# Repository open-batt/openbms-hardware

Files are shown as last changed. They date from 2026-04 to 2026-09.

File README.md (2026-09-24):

# OpenBMS






OpenBMS is an **open-source battery management system** for 2 to 7-cell Li-Ion and Li-Po battery packs. A fully integrated hardware and firmware solution for battery management and protection, providing:
-  **Fuel gauge** — measure battery capacity, state of charge, and state of health
-  **Learning algorithms** — learn battery behavior and adjust management accordingly
-  **Cell balancing** — keep multi-cell voltages in sync to prevent drift over time
-  **Protection** — guard against overcharging, overdischarging, overheating, and short circuits
-  **Communication** — talk to chargers, displays, microcontrollers, and other devices

<table>
  <tr>
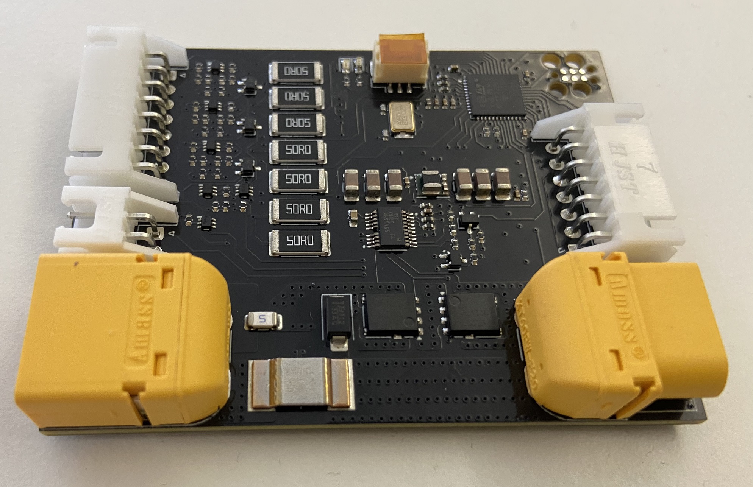
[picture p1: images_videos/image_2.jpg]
OpenBMS v3
    <td></td>
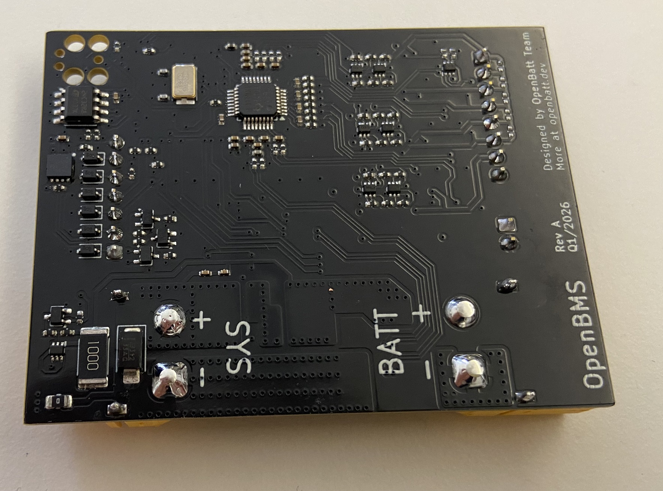
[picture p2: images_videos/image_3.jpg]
OpenBMS v4
    <td></td>
  </tr>
</table>

## Rev B is out!
Schematic and layout updated, fixes applied

## Related repositories

[OpenBMS-firmware](https://github.com/open-batt/openbms-firmware)  
[OpenBMS-test-bench](https://github.com/open-batt/openbms-test-bench-hardware)  
[OpenBMS-studio](https://github.com/open-batt/openbms-studio)

## How OpenBMS fits into system?

Battery system consists of:
- **Li-ion/Li-Po battery** — your custom 2- to 7-cell battery
- **OpenBMS** — battery management system that handles fuel gauging, cell balancing, learning algorithms, overcharge/overdischarge/overheat protection, and communication with chargers and microcontrollers
- [**Test Bench**](https://github.com/open-batt/openbms-test-bench-hardware) — a 600W dissipative resistive load for easier BMS development and testing
- **Host** — I2C/CAN interfaces, wake-up signal, can be a microcontroller, computer, etc.
- **Charger** — your custom charger, usually a CC/CV charger adjusted to your battery voltage and current
- [**OpenBMS Studio**](https://github.com/open-batt/openbms-studio) — a PC software for configuring and monitoring the BMS, visualizing data, and updating firmware using UART communication

<br/>

<video width="100%" autoplay muted loop playsinline>
  <source src="images_videos/video_2.mp4" type="video/mp4" />
</video>

## ❤️ Funding

This project is funded through [NGI0 Commons Fund](https://nlnet.nl/commonsfund), a fund established by [NLnet](https://nlnet.nl) with financial support from the European Commission's [Next Generation Internet](https://ngi.eu) program. 

[NLnet foundation logo](https://nlnet.nl)
[NGI Zero Logo](https://nlnet.nl/commonsfund)

We are very grateful to the NLnet team for helping us on our path, and we encourage you too to apply and get funds to build your project! 🚀
Learn more at the [NLnet project page](https://nlnet.nl/project/OpenBMS).

## ⚠️ Status: Work in progress

| Module | Status |
|---|---|
| OpenBMS Schematics & PCB Layout Rev A| ✅ Done |
| OpenBMS Test Bench Schematic & PCB Layout | ✅ Done |
| Revision B (Hardware improvements) |  ✅ Done |
| BMS, Test Bench & Battery Tests |  🚧 In progress |
| Documentation & Final Release | 🚧 In progress |

## Features

- 🔋 Supports pack voltages up to 30V and continuous currents up to 16A.
- ⚡ State of Charge (SoC) estimation using coulomb counting
- 🩺 State of Health (SoH) monitoring with capacity fade tracking and internal resistance estimation
- 📊 Per-cell voltage monitoring with 24-bit resolution
- 🔌 Pack and cell overcurrent protection up to 20A hardware trip (adjustable threshold)
- 🛡️ Overvoltage and undervoltage protection (adjustable thresholds)
- 🔀 Passive cell balancing for up to 7 cells
- 🔵 Battery current measurement via precision shunt resistor
- 🌡️ NTC thermistor input for battery temperature monitoring
- 🌡️ On-board ambient temperature monitoring via MCU and ADC internal sensors
- 💾 Non-volatile storage of SoC, SoH, impedance, fault history, and charge profiles (EEPROM)
- 🚌 CAN bus communication interface (up to 1 Mbit/s)
- 🔗 I2C communication interface for host integration (SMBus compatible)
- 🖥️ UART debug interface
- 🔔 Wake-up input with power-on latch for low-power system control
- 🔋 Power-down mode quiescent current < 2 µA
- 🖥️ Based on STM32L431 ARM Cortex-M4 microcontroller
  
## Overview
First, a small introduction to the project structure:
```
+-------------+       +---------------------------+       +----------------+
|             |       |         OpenBMS           |       |                |
|   Battery   |       | - - - - - - - - - - - - - |       |     System     |
| 2-7S Li-Ion | cells |   +-------+   +-------+   |       |                |
| 2-7S Li-Po  |- - - >|   |  ADC  |   |  MCU  |   |<----->|    host/load   |
|             |       |   +-------+   +-------+   | comms |                |
|             |<=====>|   +-------+   +-------+   |<=====>|     Charger    |
|             |  pwr  |   | Power |   | FETs  |   |  pwr  |                |
+-------------+       |   +-------+   +-------+   |       +----------------+
                       +-----------+--------------+
```

OpenBMS and the battery are designed to be a single, inseparable unit. Ideally, it is
connected on the first day of the battery's life and stays throughout its entire lifetime.
This way, OpenBMS learns the battery's characteristics over time and continuously tracks
its state of health and other parameters.
 
It protects the battery from overcurrent, overvoltage, and undervoltage conditions, and
balances cells to maximize pack lifetime. State of charge estimation tells you exactly how
much energy you have left, while long-term health monitoring tells you when it's time to
replace the battery.
 
The battery communicates with the host system via CAN bus or I2C. Through OpenBMS, the battery can:
- Give energy to the system (discharge)
- Take energy from the system (charge)
 
OpenBMS can be easily described with the following block diagram:

```
+---------------------------------------------------------------------------------------------------------------+
|                                                  OpenBMS                                                      |
|                                                                                                               |
|  +-----------------------+     power     +-------------------+     power     +-------------------------+      |
|  |    Battery Input      |<=============>|  Switch Circuit   |<=============>|         Output          |      |
|  | - - - - - - - - - - - |               | - - - - - - - - - |               | - - - - - - - - - - - - |      |
|  | + XT60 pwr connector  |               | + Main NFETs      |               | + XT60 pwr connector    |      |
|  | + 8-pin JST (balancer)|               | + Precharge FETs  |               | + JST (I2C,CAN,WAKE_UP) |      |
|  | + 2-pin JST (NTC)     |               +--------+----------+               +-------------------------+      |
|  +-----------------------+                         |                                      ^                   |
|            |                                       | ctr signals                          | can, i2c, wake_up |
|            | cells                                 v                                      |                   |
|  +---------------------+       SPI      +-------------------------+                       |                   |
|  |    Analog Block     |<==============>|     Digital Block       |=======================+                   |
|  |     (ADS131M08)     |                | - - - - - - - - - - - - |                                           |
|  | - - - - - - - - - - |                | + STM32L431 (Cortex-M4) |                                           |
|  | + Cell voltage x7   |                | + EEPROM                |                                           |
|  | + Pack voltage      |                | + LED indicators        |                                           |
|  | + Current           |                | + SWD / UART debug      |                                           |
|  | + PFETs cell switch |                | + I2C / CANinterfaces   |                                           |
|  +---------------------+                +-------------------------+                                           |
|                                                     ^                                                         |
|                                                     | 3.3V, wake_up                                           |
|                                          +----------+---------+                                               |
|                                          | 3.3V Power Supply  |                                               |
|                                          | - - - - - - - - -  |                                               |
|                                          | + Buck converter   |                                               |
|                                          | + Enable latch     |                                               |
|                                          +--------------------+                                               |
|                                                                                                               |
+---------------------------------------------------------------------------------------------------------------+
```

## Characteristics

| Parameter | Value |
|---|---|
| Cell count | 2 to 7 cells |
| Supported chemistries | Li-Ion, Li-Po |
| Communication interfaces | CAN bus (up to 1 Mbit/s), I2C (SMBus compatible)  |
| Maximum pack voltage | 30.1V (7 cells × 4.3V) |
| Minimum pack voltage | 4V (2 cells × 2V) |
| Maximum continuous current | 16A |
| Maximum peak current | 20A (hardware trip) |
| Current consumption (active, 7-cell, max) | 6mA |
| Current consumption (active, 7-cell, typ) | 4mA |
| Current consumption (active, 2-cell, max) | 19mA |
| Current consumption (active, 2-cell, typ) | 13mA |
| Power-down quiescent current | < 2 µA |
| Operating temperature range | -40°C to 85°C |

## License

OpenBMS is licensed under the MIT license and CERN OHL-S v2.

Check [openbatt.dev](https://openbatt.dev) for more!

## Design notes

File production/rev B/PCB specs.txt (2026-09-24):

Layers: 4
PCB thickness: 1.6mm
Min hole size: 0.3mm
Surface finish:  HASL lead free
Min track/spacing:  6/6mil
Solder mask: purple
Silkscreen: white
Finished copper:  1 oz Cu (Inner Copper:1 oz)

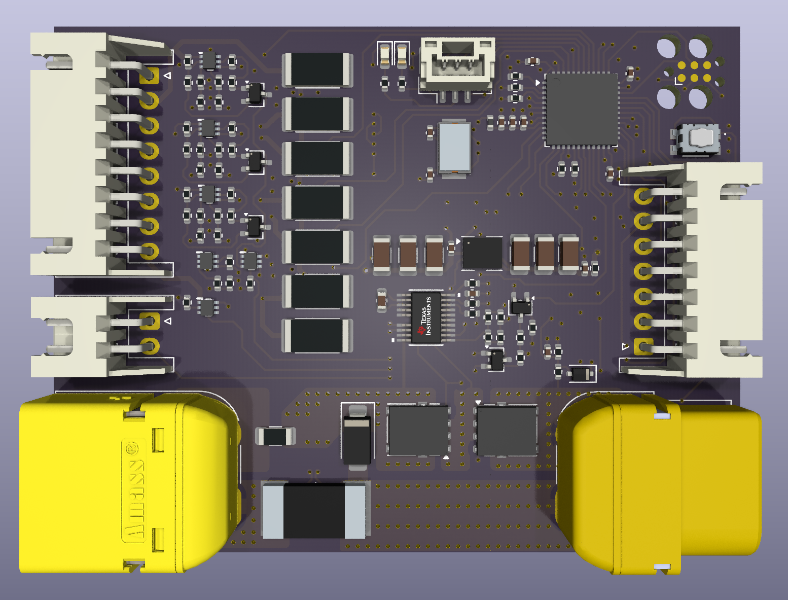
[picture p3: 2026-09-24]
production/rev B/openbms-img-1.PNG

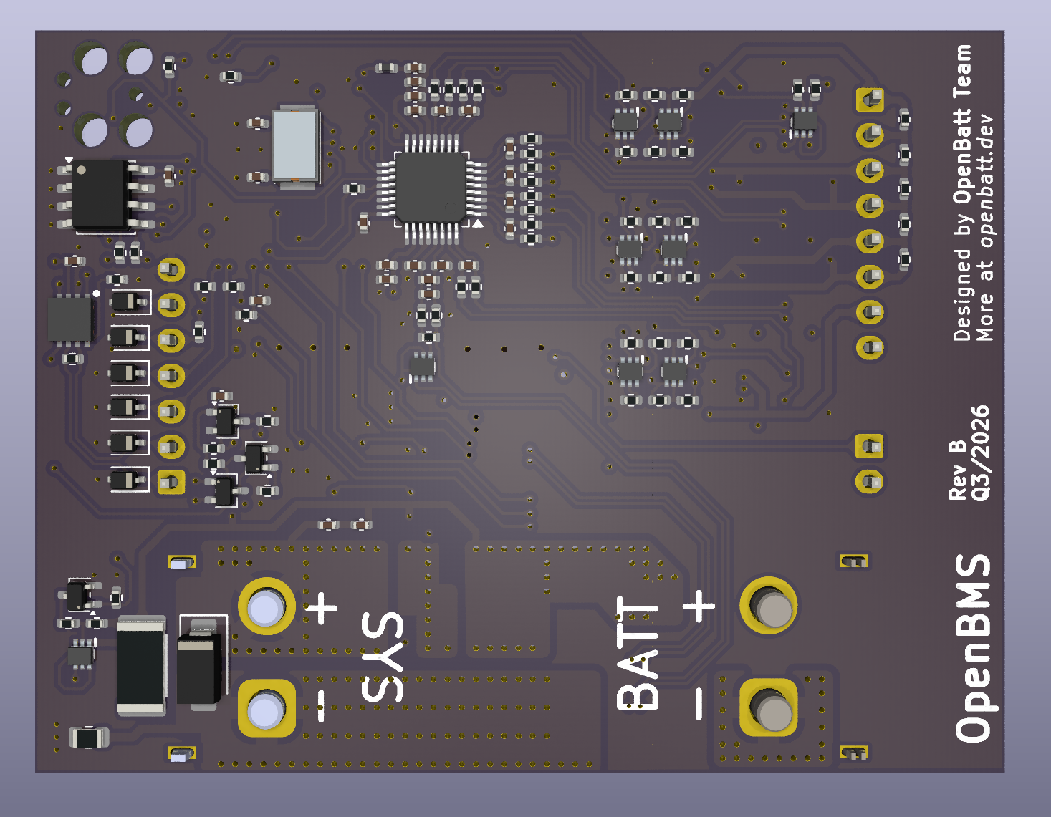
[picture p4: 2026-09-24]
production/rev B/openbms-img-2.PNG

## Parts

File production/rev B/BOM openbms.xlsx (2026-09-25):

Reference | Qty | Value | Manufacturer_Part_Number | Package
C1,C2,C4,C6,C8,C10,C11,C12,C13,C15,C17,C18,C20,C21,C22,C23,C25,C29,C30,C31,C32,C39,C43,C45 | 24 | 100n | GRM155R71A104KA01D | 0402
C3 | 1 | 100p | CL05C101JB5NNNC | 0402
C5,C9,C26,C34 | 4 | 1u | C0402C105K8PACTU | 0402
C7,C24,C35,C44 | 4 | 10n | C0402C103K5REC7411 | 0402
C14,C16,C27,C28 | 4 | 18pF | GRM1555C1H180JA01D | 0402
C19 | 1 | 220n | GRM155R71A224KE01J | 0402
C33 | 1 | 220n | CL10E224KA84PNC | 0603
C36,C37,C38,C40,C41,C42 | 6 | 10u | CL31A106MBHNNNE | 1206
D1,D2,D3,D14 | 4 | SBAT54CWT1G | SBAT54CWT1G | SOT-323
D4 | 1 | Green LED | LTST-C190GKT | 0603
D5 | 1 | Red LED | LTST-C190KRKT | 0603
D6,D7 | 2 | TVS diode P4SMA33A-Q | P4SMA33A-Q | DO-214AC
D8,D9,D10,D11,D12,D13 | 6 | TVS diode DBLC03CIQ-7 | DBLC03CIQ-7 | SOD-323
D15 | 1 | BAT54J | BAT54J | SOD-323
F1 | 1 | 25A Fuse | SF-1206HV25M-2 | 1206
J1 | 1 | 3-pin JST connector | BM03B-GHS-TBT | 3-pin JST connector
J3 | 1 | 8-pin JST connector | S8B-XH-A | 8-pin JST connector
J4 | 1 | 2-pin JST connector | S2B-XH-A | 2-pin JST connector
J5 | 1 | XT60PW-M connector | XT60PW-M | XT60PW-M connector
J6 | 1 | XT60PW-F connector | XT60PW-F | XT60PW-F connector
J7 | 1 | 7-pin JST connector | S7B-XH-A | 7-pin JST connector
L1,L2 | 2 | 600R @ 100MHz | BLM15PX601SN1D | 0402
Q1,Q2 | 2 | NTMFS5C612NLT1G | NTMFS5C612NLT1G | 5-DFN (5x6) (8-SOFL)
Q3,Q6 | 2 | BSS84AKW,115 | BSS84AKW,115 | SOT-323
Q4,Q5,Q7 | 3 | 2N7002KW | 2N7002KW | SOT-323
R1,R2,R3,R4,R6,R7,R9,R14,R21,R22,R25,R29,R30,R31,R34,R35,R49,R50,R54,R58,R62,R63,R64,R65,R66,R91,R92,R93,R94,R96,R98,R102,R109,R110,R111,R112,R116,R119 | 38 | 100k | RC0402FR-07100KL | 0402
R5,R8 | 2 | 100R | RMCF0402FT100R | 0402
R10,R11,R41,R42,R67,R68,R74 | 7 | 50R | RNCL2512FT50R0 | 2512
R12,R13,R27,R28,R56,R57,R69 | 7 | 68k,0.1% | RT0402BRD0768KL | 0402
R15,R16,R36,R37,R60,R61,R73 | 7 | 2k,0.1% | RT0402BRD072KL | 0402
R17,R20,R23,R24,R26,R32,R33,R43,R45,R48,R51,R55,R59 | 13 | 1k,0.1% | RT0402BRD071KL | 0402
R18,R19,R52,R53,R70,R71,R72,R75,R76,R78,R86,R99,R101,R117,R118 | 15 | 10k | RMCF0402FT10K0 | 0402
R38,R39,R40,R44 | 4 | 33R | RC0402FR-0733RL | 0402
R46,R47 | 2 | 100R | RC0402FR-07100RL | 0402
R77 | 1 | 330R,0.1% | RT0402BRD07330RL | 0402
R79,R80 | 2 | 470R | RC0402FR-07470RL | 0402
R81,R87,R100,R108,R113 | 5 | 0R | CR0402AJ/-000GAS | 0402
R82,R83,R84,R88,R89 | 5 | 4.7k | RC0402JR-074K7L | 0402
R85 | 1 | 120R | CRCW0402120RFKEDC | 0402
R90 | 1 | 100R | 3521100RFT | 2512
R95 | 1 | 261k | RC0402FR-07261KL | 0402
R97 | 1 | 137k | RC0402FR-07137KL | 0402
R103 | 1 | 2m | SEWF3920D2L00P9 | 3920
R115 | 1 | 0R | RMCF0805ZT0R00 | 0805
SW1 | 1 | Button | 435451019820 | 4.60mm x 2.80mm
U1,U2,U4,U6,U8,U9,U10,U18 | 8 | DMP68D1LVQ-7 | DMP68D1LVQ-7 | SOT-563
U3,U7,U11,U12,U13,U14,U22 | 7 | DMN601VK-7 | DMN601VK-7 | SOT-563
U5 | 1 | ADS131M08xPBS | ADS131M08IPBS | 32-TQFP
U15 | 1 | STM32L431CCUx | STM32L431CCU6TR | 48-UFQFPN
U16 | 1 | TCAN3413DRBR | TCAN3413DRBR | 8-VDFN
U17 | 1 | 256kbit EEPROM memory | M24256-DRMN8TP/K | 8-SOIC
U19 | 1 | TPS12000QDGXRQ1 | TPS12000QDGXRQ1 | 19-VSSOP
U20 | 1 | LMZM23600V3 | LMZM23600V3SILR | 3.8 x 3
Y1 | 1 | 8.192MHz | ECS-81.92-12-30Q-EN-TR | 5.0 x 3.2
Y2 | 1 | 8MHz | ECS-80-12-30Q-DS-TR | 5.0 x 3.2

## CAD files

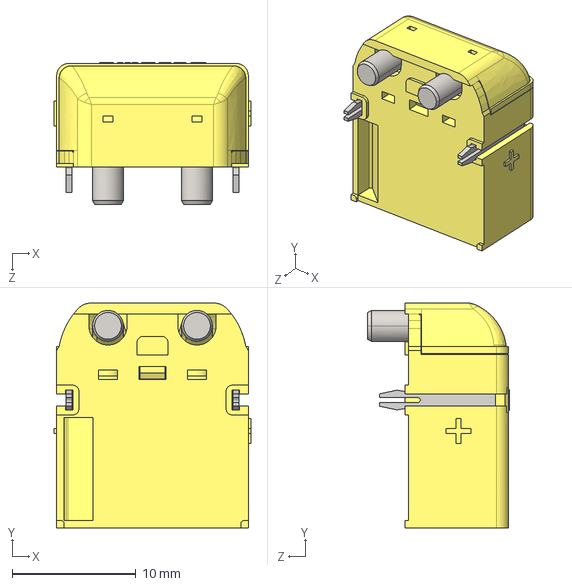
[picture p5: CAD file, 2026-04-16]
openbms/3D models/XT60PW-M.stp
15.9 x 18.2 x 11.5 mm

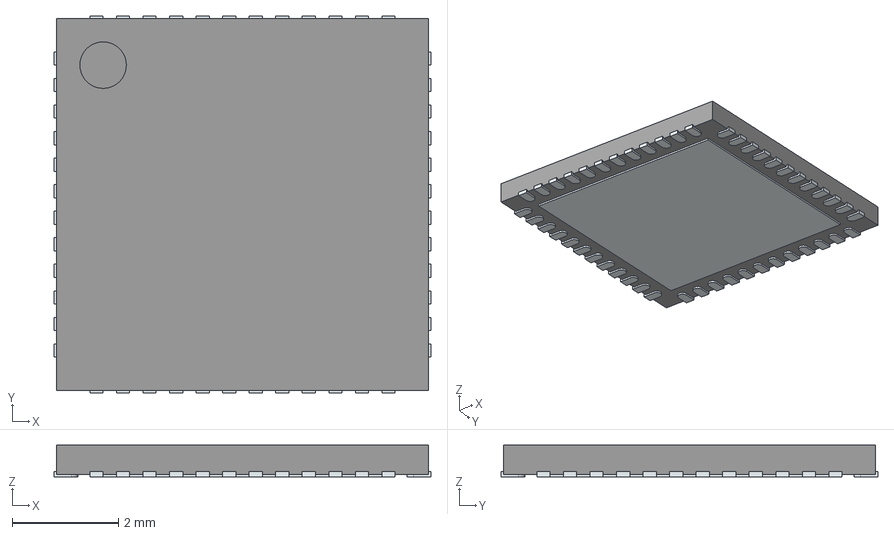
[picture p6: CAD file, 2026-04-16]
openbms/3D models/STM32L431CCU6.stp
7.10 x 7.10 x 0.6 mm
ThermalPin
PinsArrayLR
PinsArrayTB

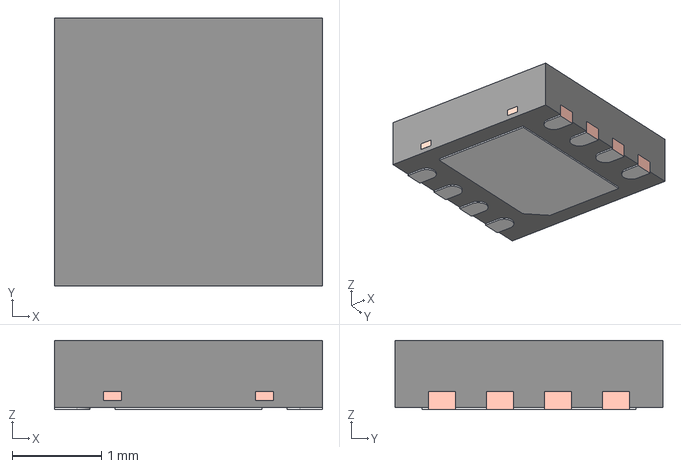
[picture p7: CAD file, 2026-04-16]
openbms/3D models/TCAN3413DRBR.stp
3.00 x 3.00 x 0.775 mm
BODY-SON
FRAME-DRB0008B

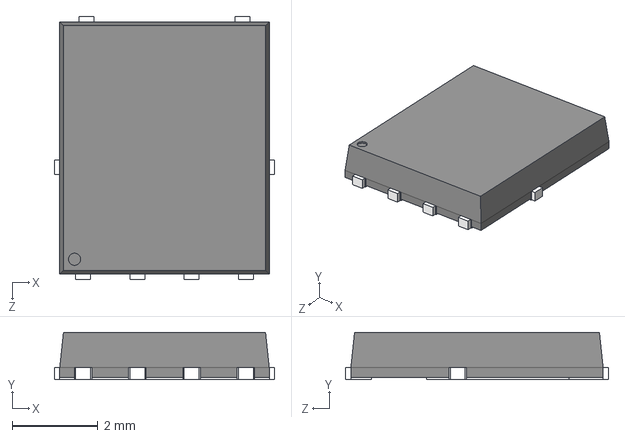
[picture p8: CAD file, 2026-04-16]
openbms/3D models/NTMFS5C612NLT1G.stp
5.15 x 1.10 x 6.15 mm

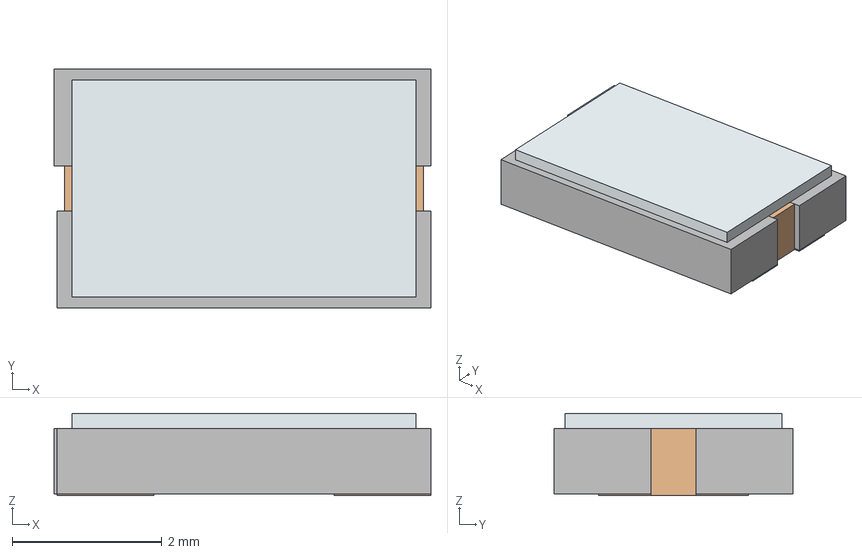
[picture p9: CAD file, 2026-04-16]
openbms/3D models/ECS-81.92-12-30Q-EN-TR.stp
5.04 x 3.20 x 1.10 mm
solidBody
solidBody1
solidLead

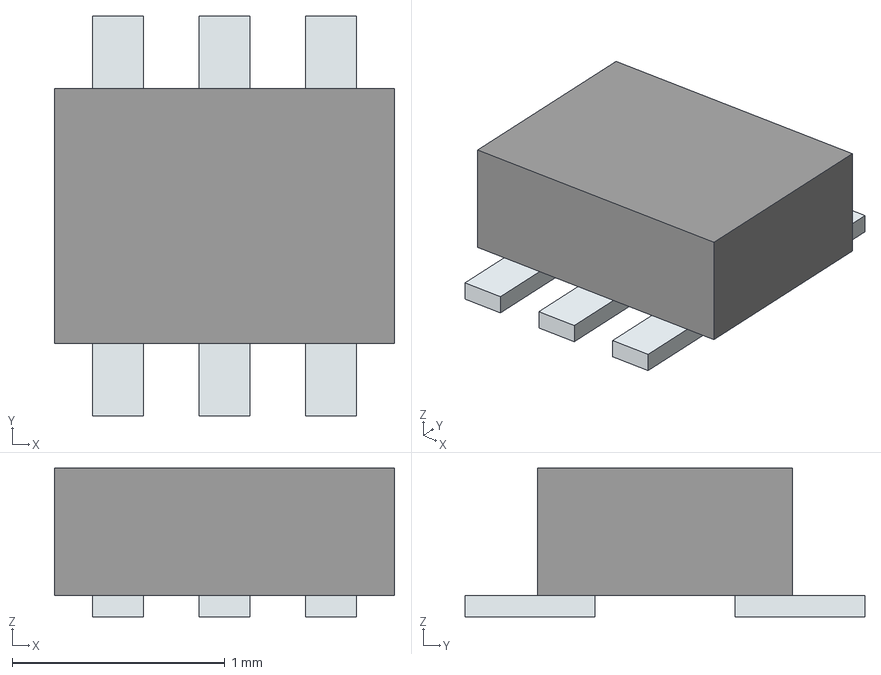
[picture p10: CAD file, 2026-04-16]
openbms/3D models/DMN601VK-7.stp
1.60 x 1.88 x 0.7 mm
Pins

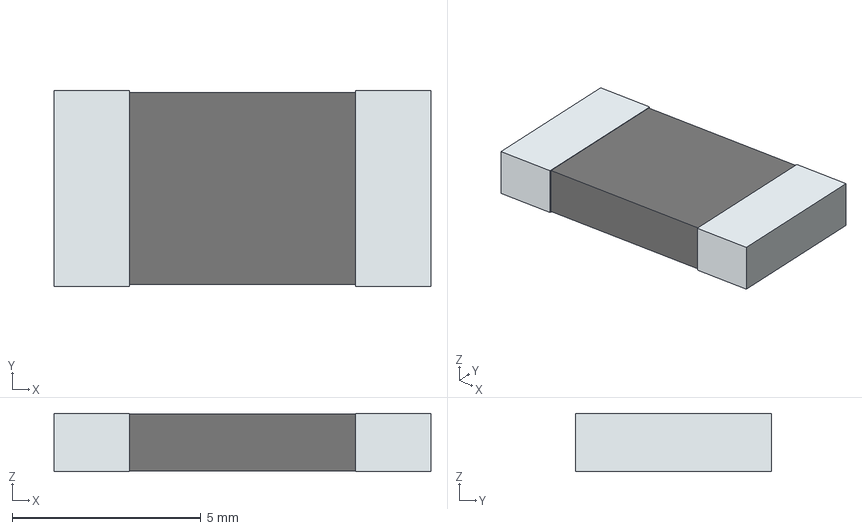
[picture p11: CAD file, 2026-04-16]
openbms/3D models/SEWF3920D2L00P9.stp
10.0 x 5.20 x 1.55 mm
term1
term2

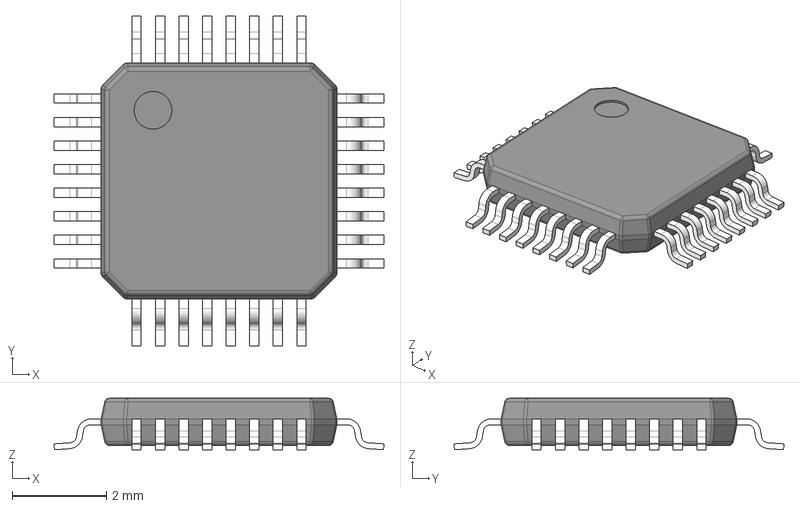
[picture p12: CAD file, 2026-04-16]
openbms/3D models/ADS131M08IPBSR.stp
7.00 x 7.00 x 1.09 mm
BODY-TQFP
LEAD-TQFP x 32
PIN1

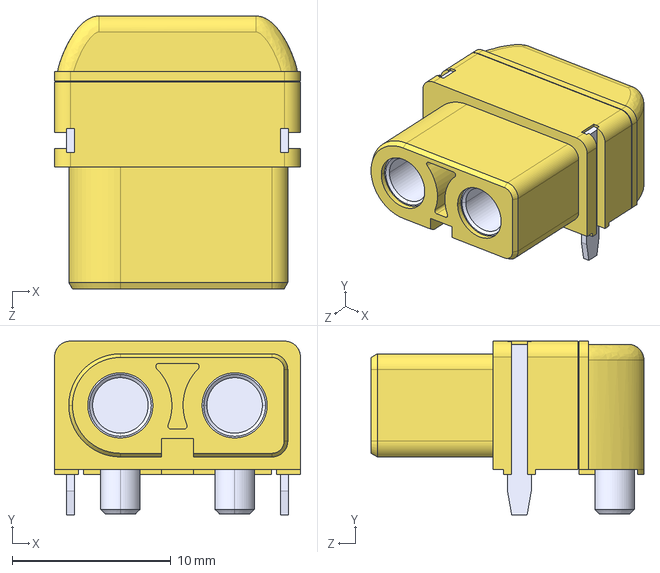
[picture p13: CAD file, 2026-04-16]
openbms/3D models/XT60PW-F.stp
15.5 x 11.0 x 17.2 mm

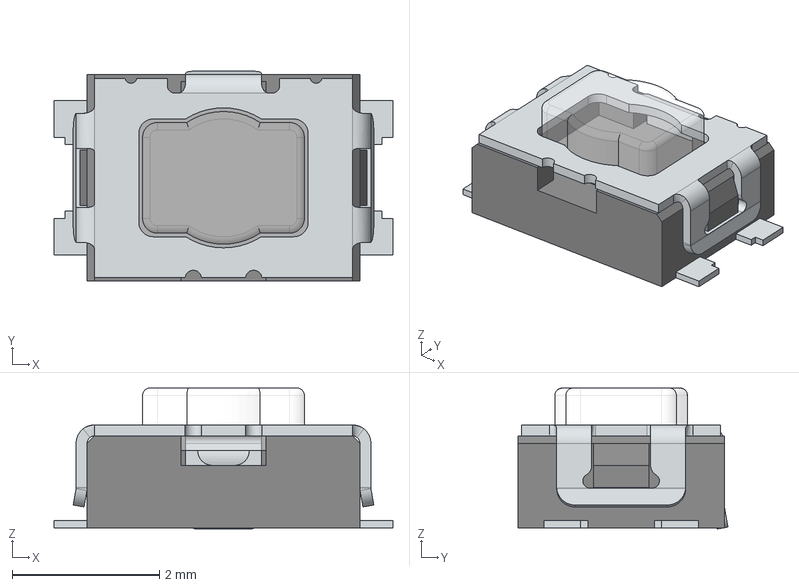
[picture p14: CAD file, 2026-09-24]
openbms/3D models/435451019820.stp
4.60 x 2.85 x 1.91 mm
Frame
Cover
Terminal
Button

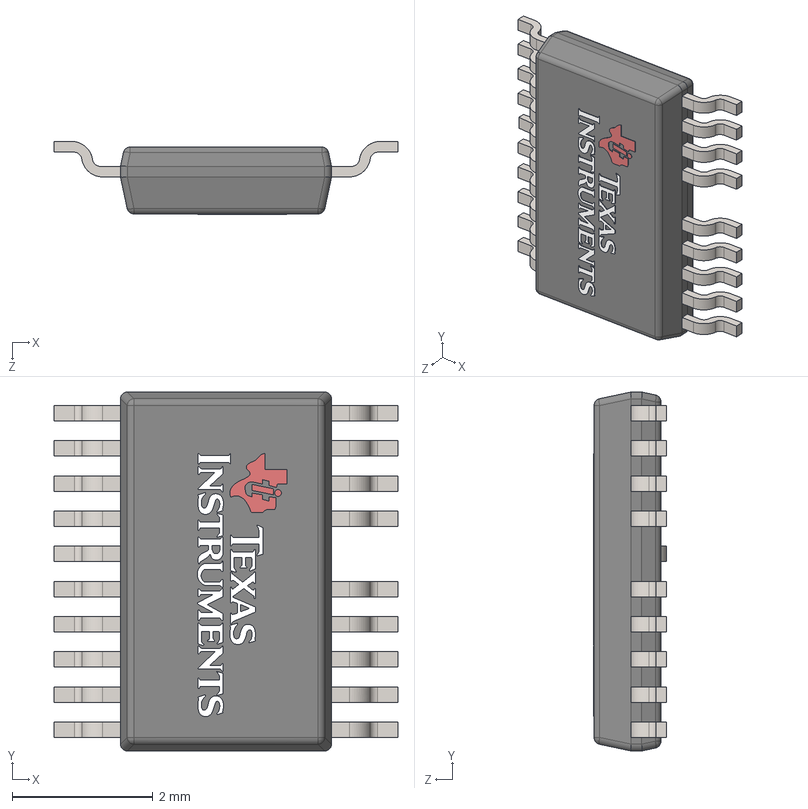
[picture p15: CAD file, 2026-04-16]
openbms/3D models/TPS12111LQDGXRQ1.stp
4.88 x 5.10 x 1.04 mm
TPS12111LQDGXRQ1
TPS12111LQDGXRQ1_4
TPS12111LQDGXRQ1_16
TPS12111LQDGXRQ1_6
TPS12111LQDGXRQ1_3
TPS12111LQDGXRQ1_7
TPS12111LQDGXRQ1_5
TPS12111LQDGXRQ1_10
TPS12111LQDGXRQ1_17
TPS12111LQDGXRQ1_8
TPS12111LQDGXRQ1_15
TPS12111LQDGXRQ1_2
TPS12111LQDGXRQ1_11
TPS12111LQDGXRQ1_19
TPS12111LQDGXRQ1_18
TPS12111LQDGXRQ1_9
TPS12111LQDGXRQ1_12
TPS12111LQDGXRQ1_14
TPS12111LQDGXRQ1_1
TPS12111LQDGXRQ1_13
Texas Instruments

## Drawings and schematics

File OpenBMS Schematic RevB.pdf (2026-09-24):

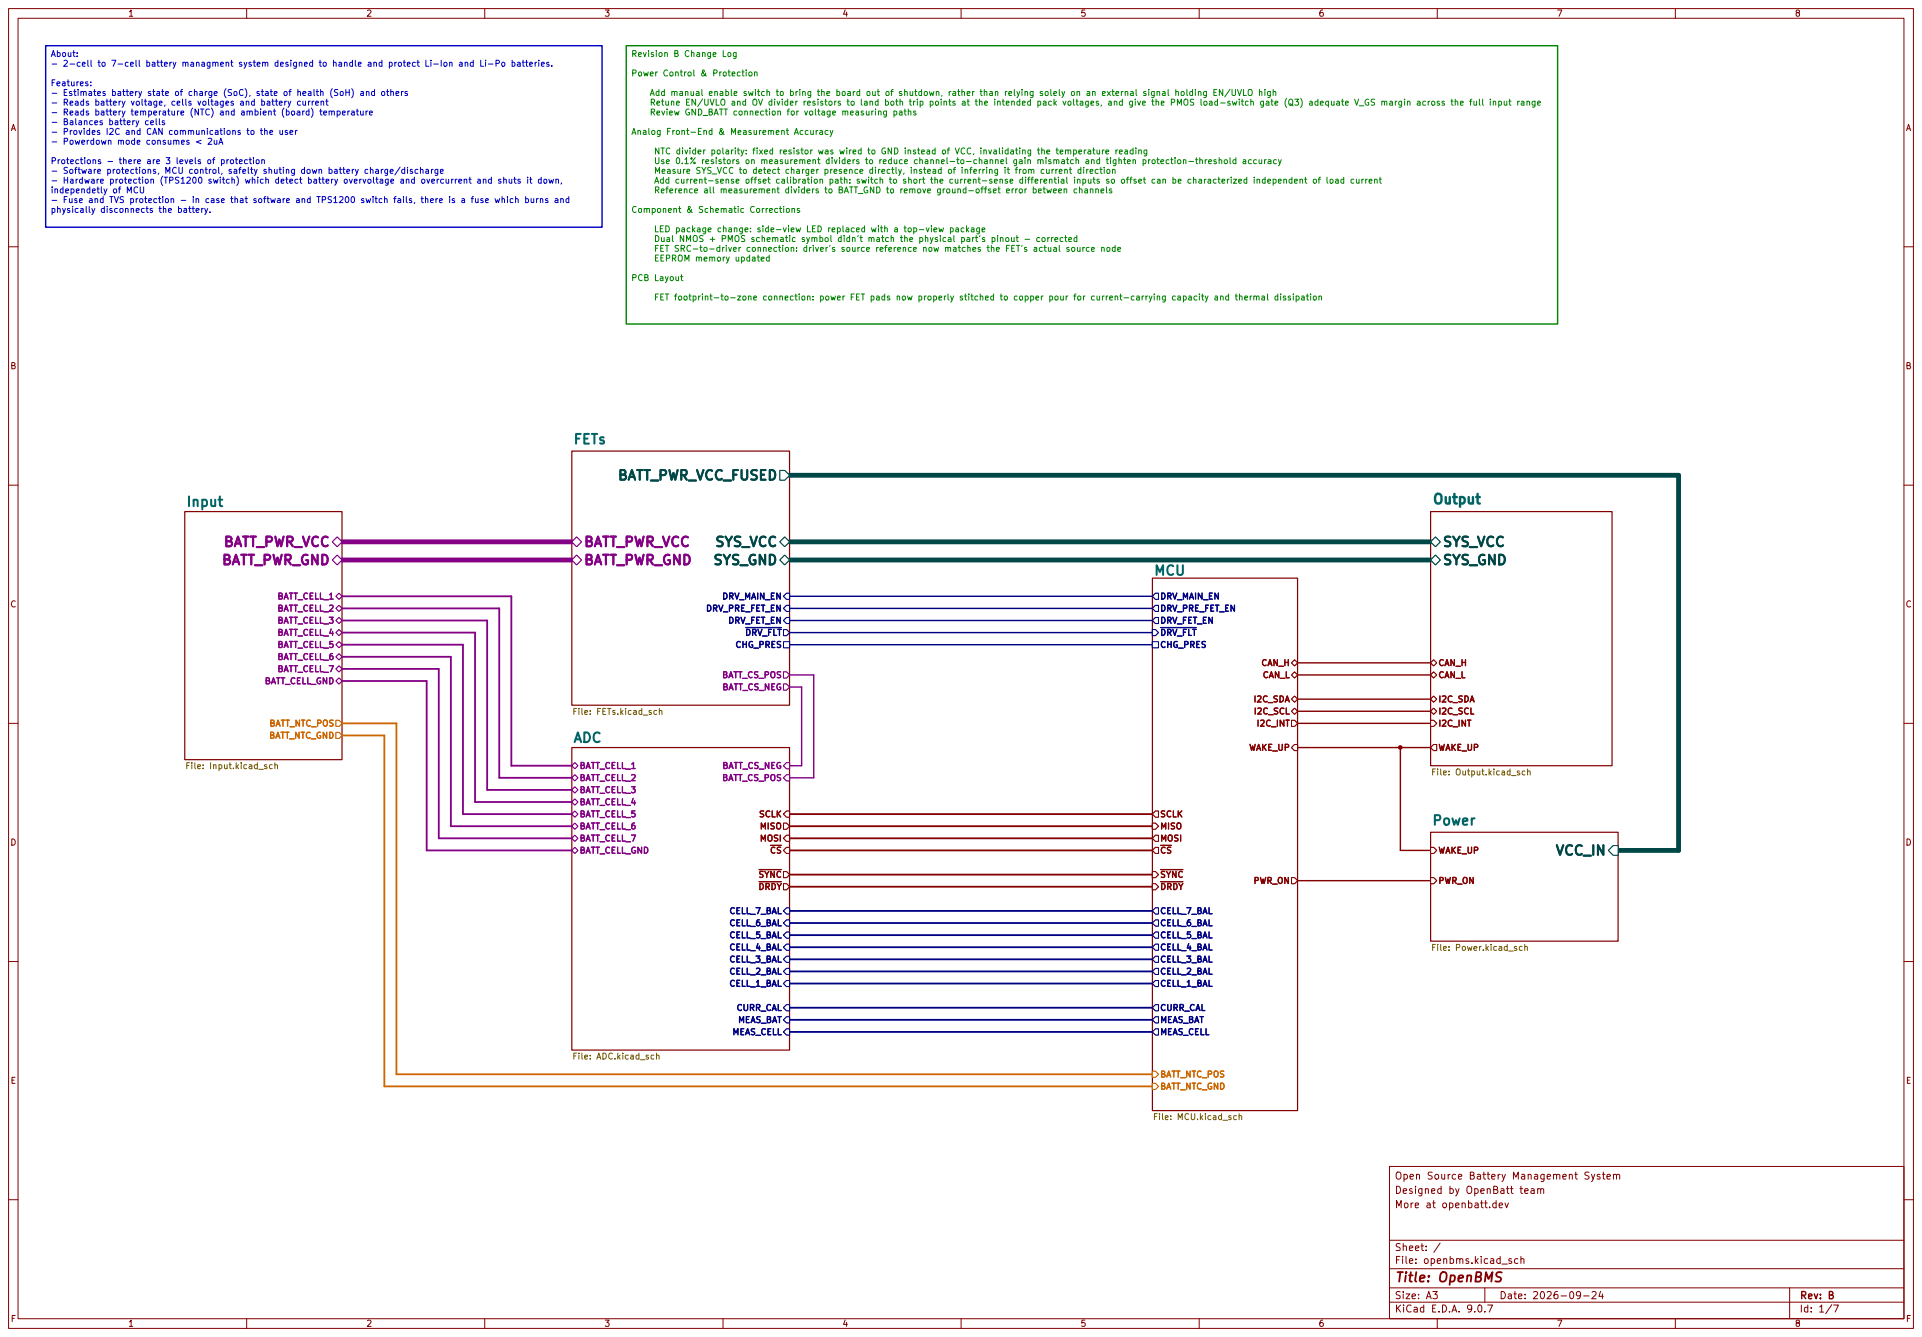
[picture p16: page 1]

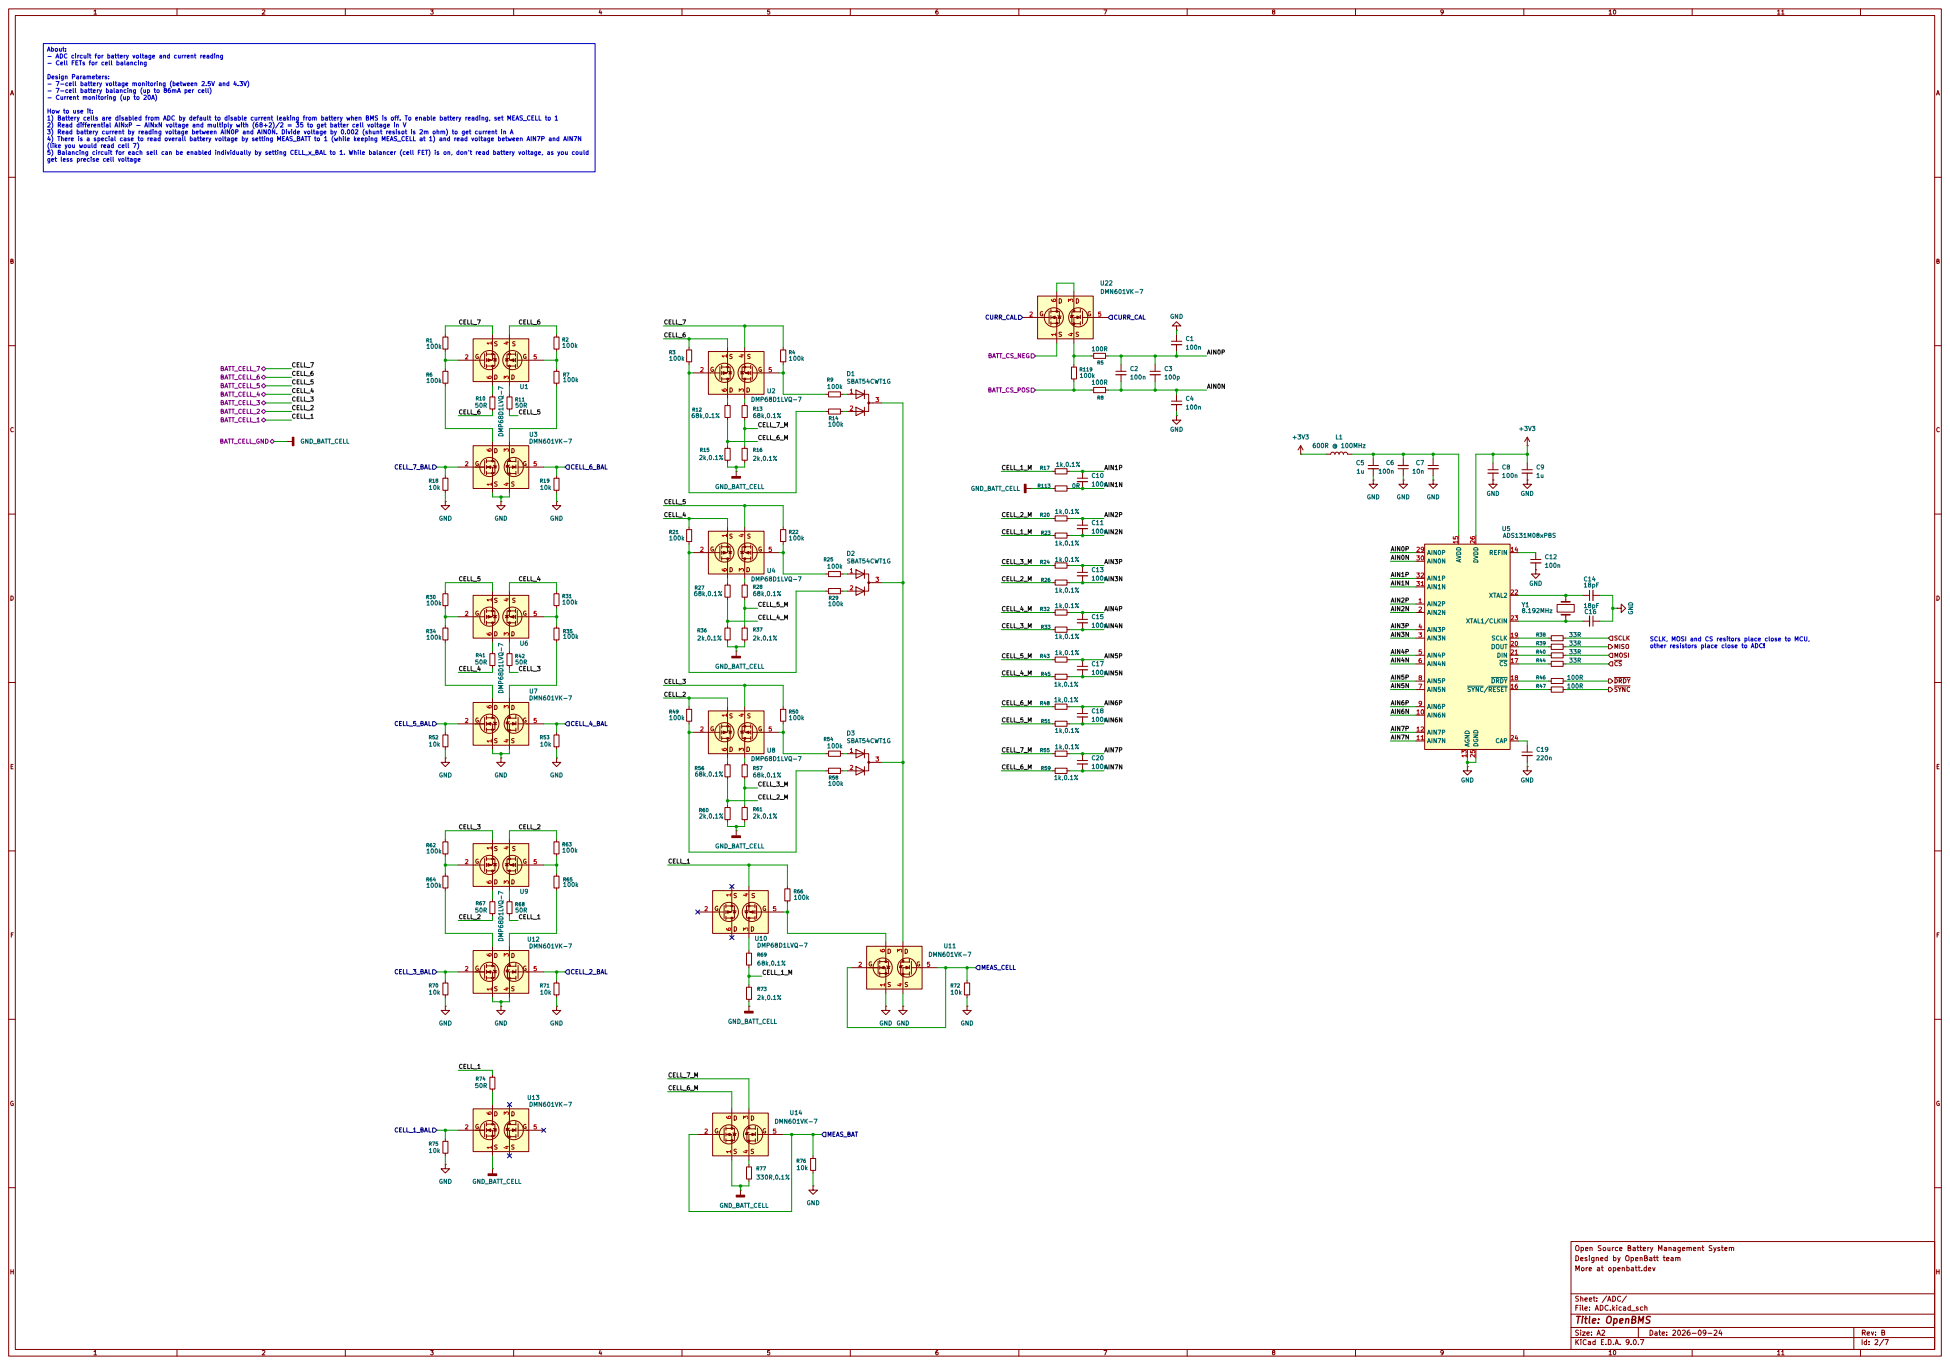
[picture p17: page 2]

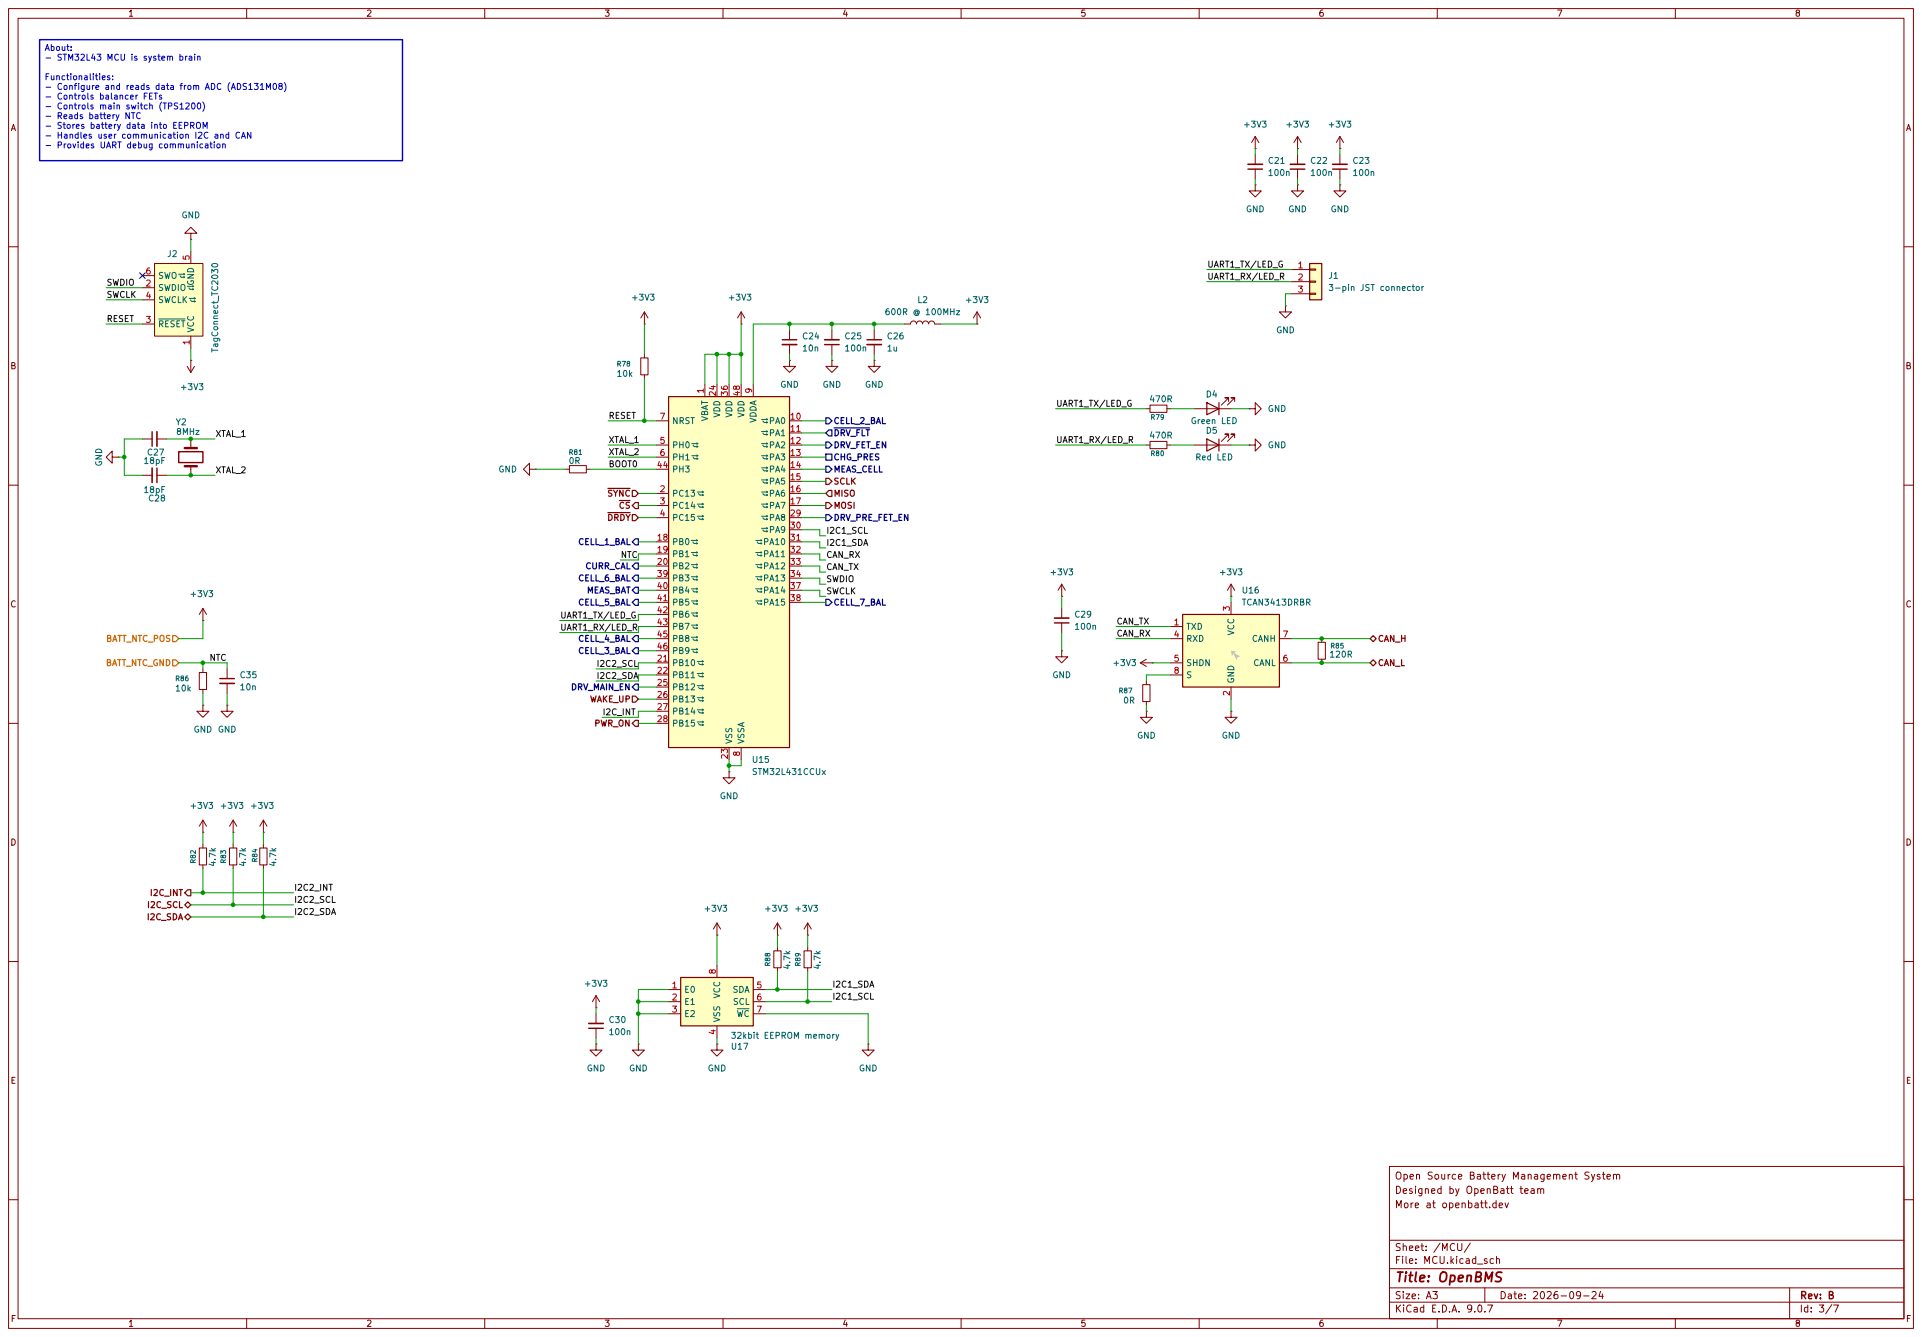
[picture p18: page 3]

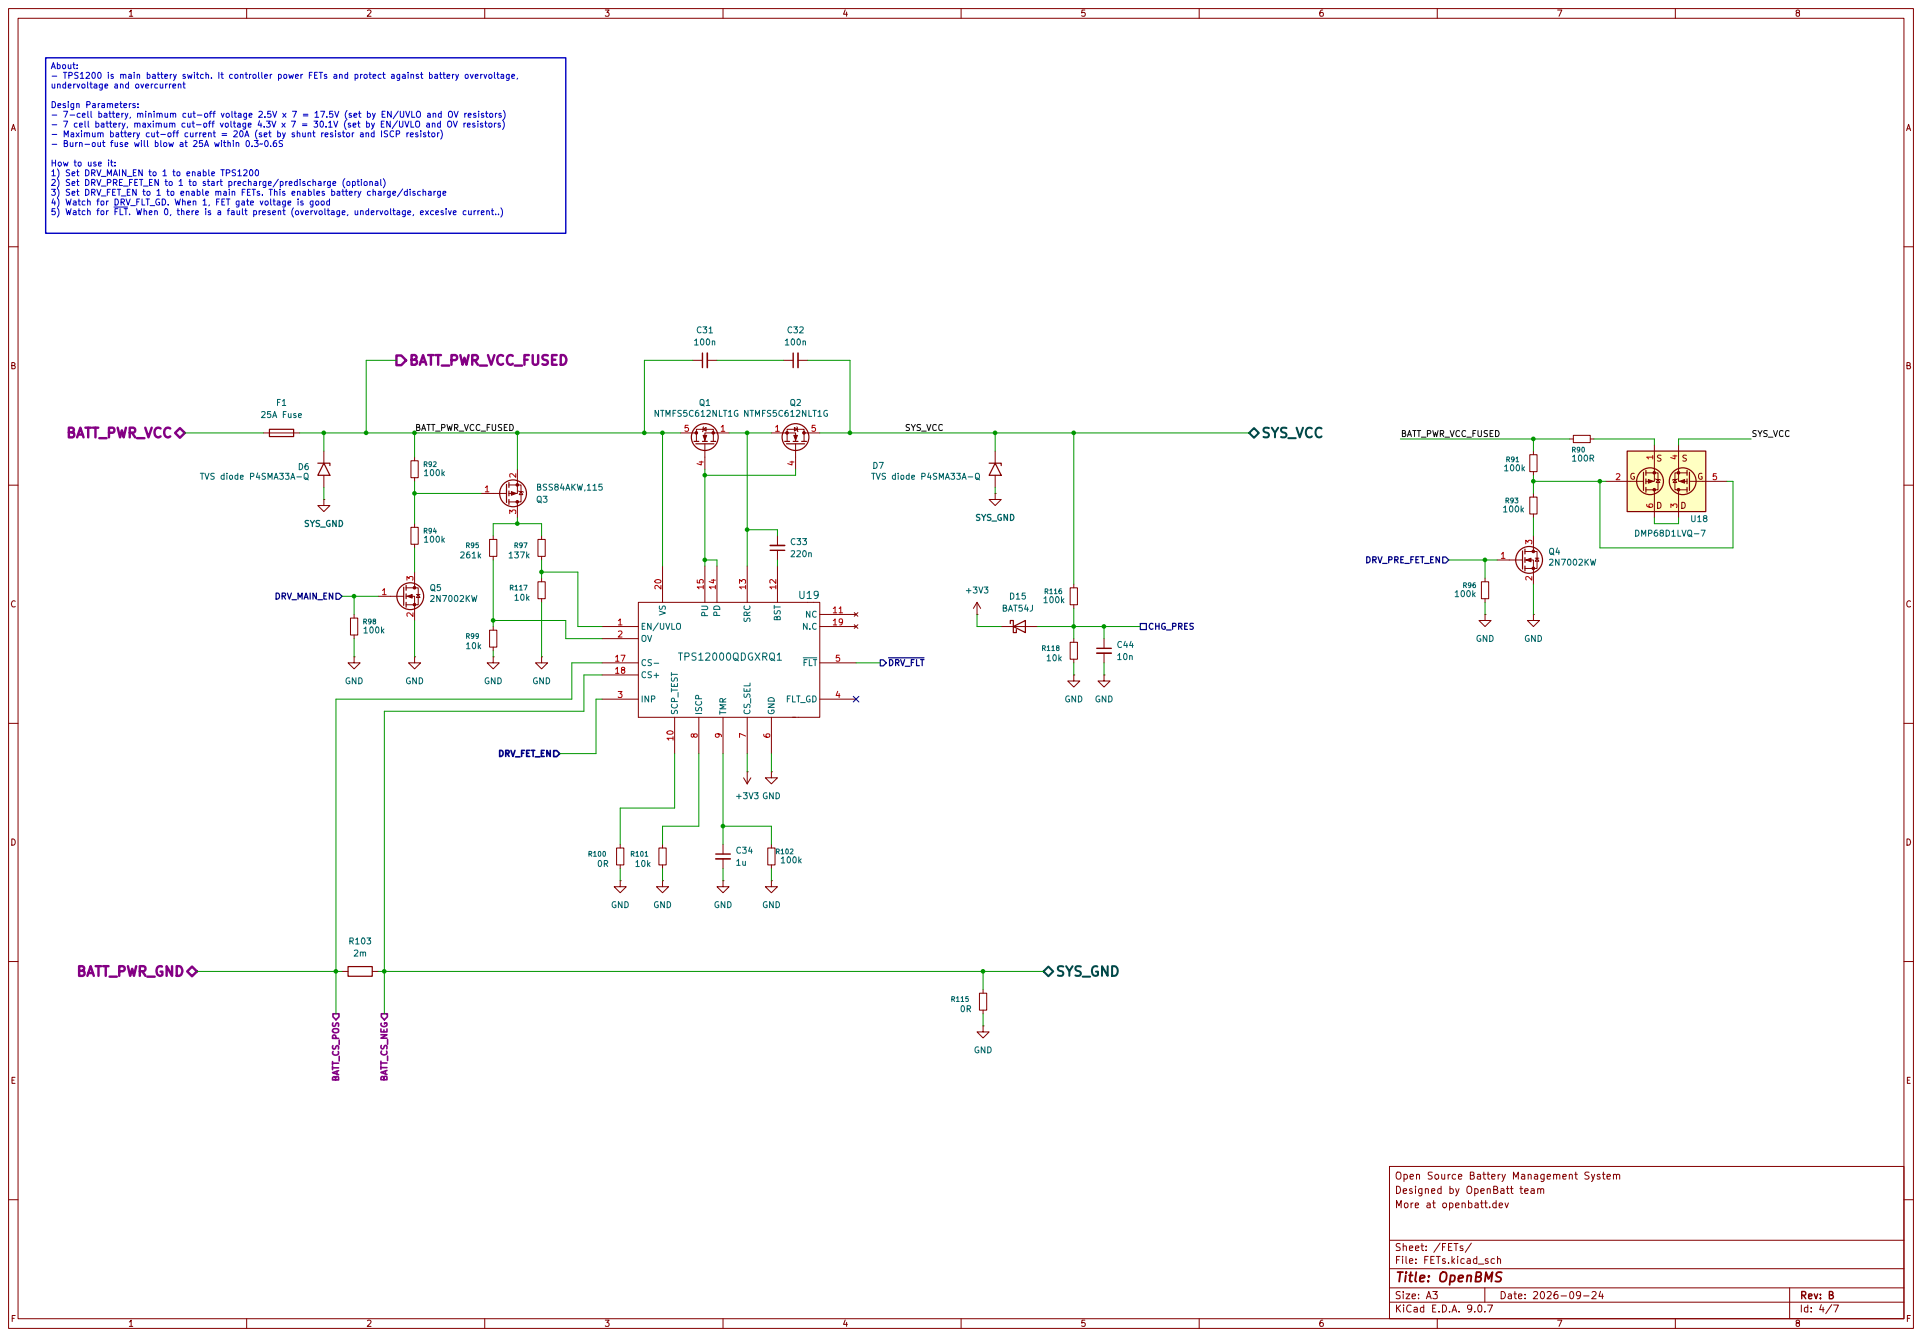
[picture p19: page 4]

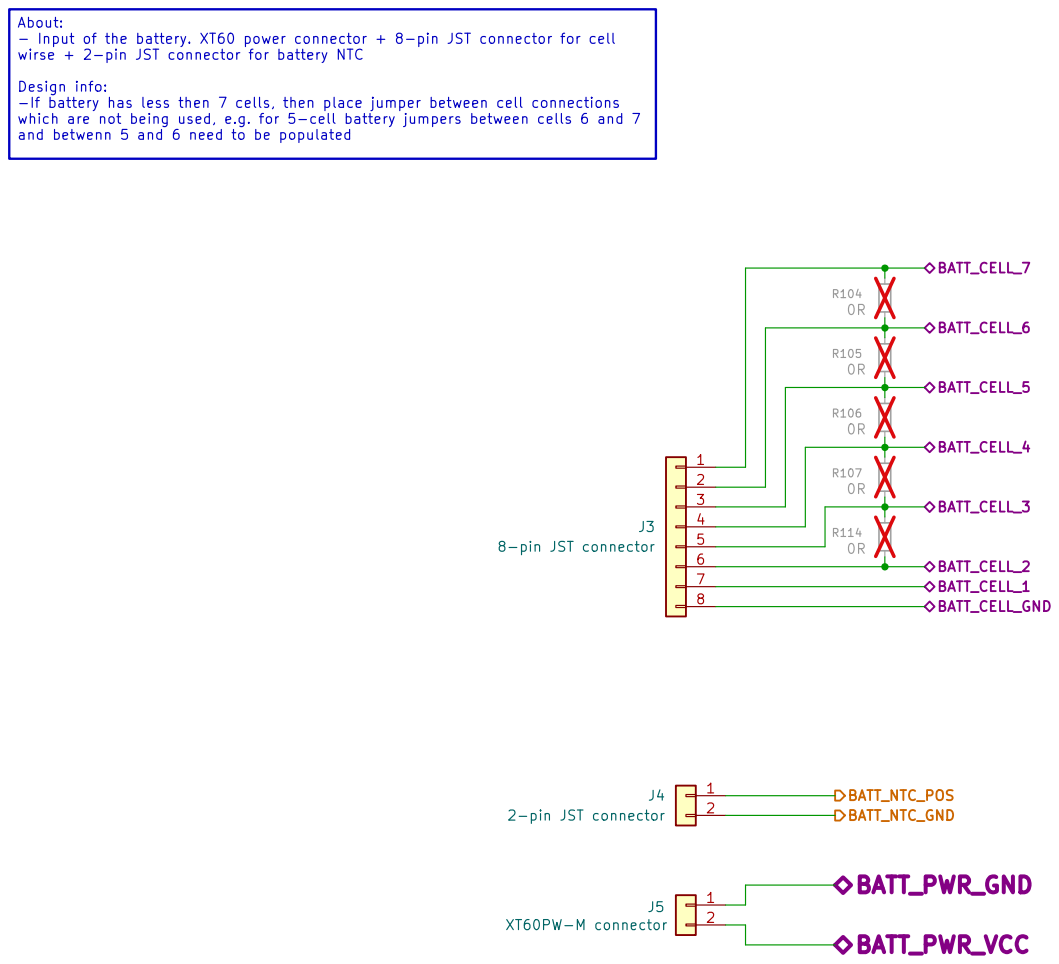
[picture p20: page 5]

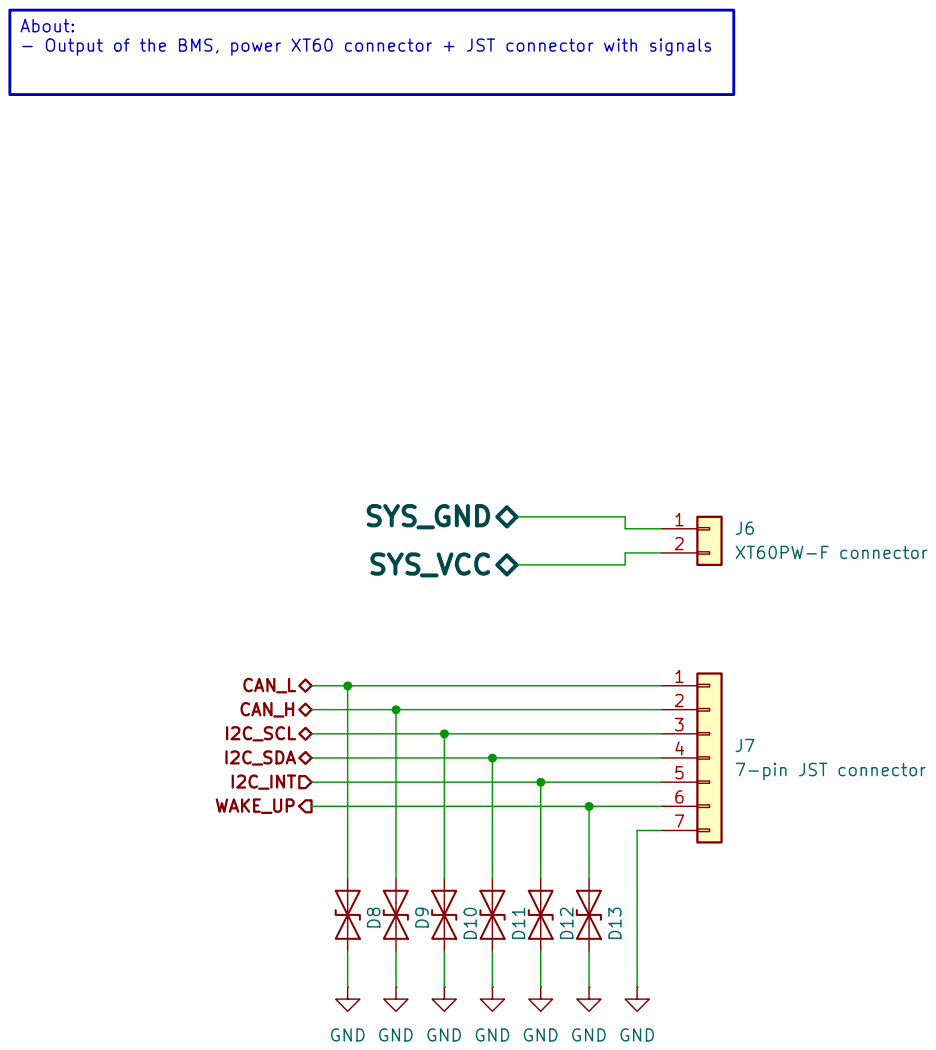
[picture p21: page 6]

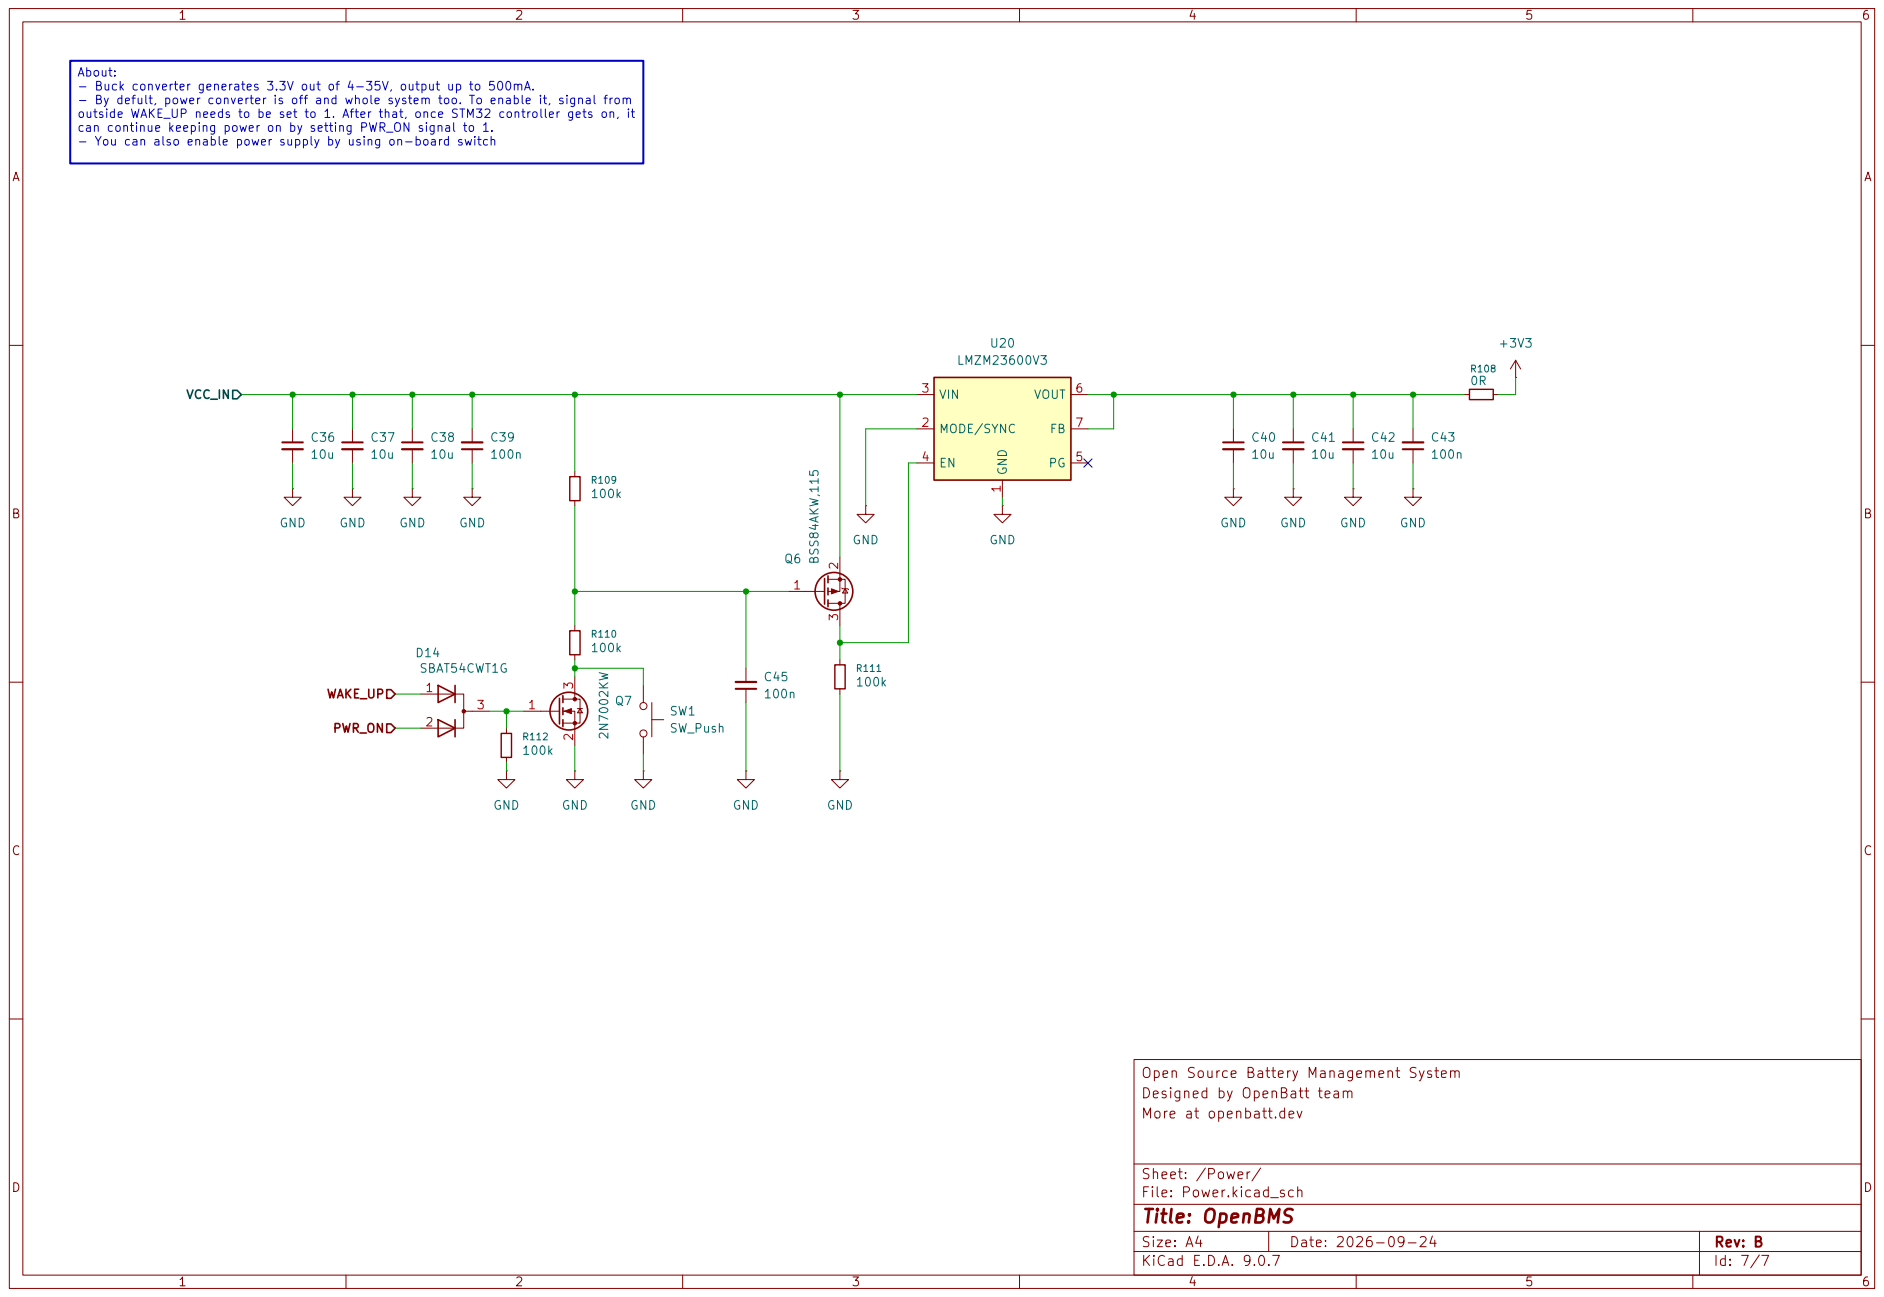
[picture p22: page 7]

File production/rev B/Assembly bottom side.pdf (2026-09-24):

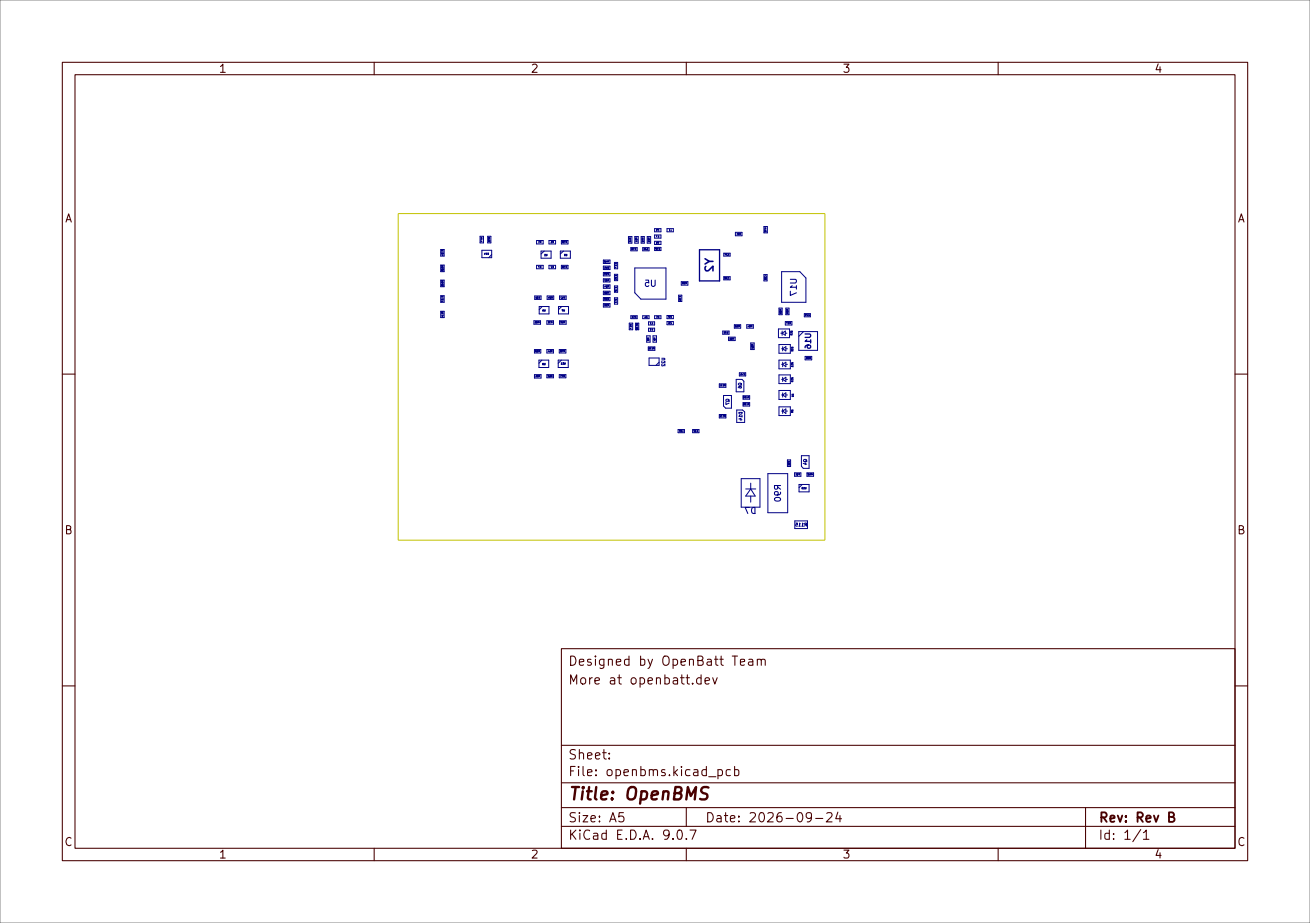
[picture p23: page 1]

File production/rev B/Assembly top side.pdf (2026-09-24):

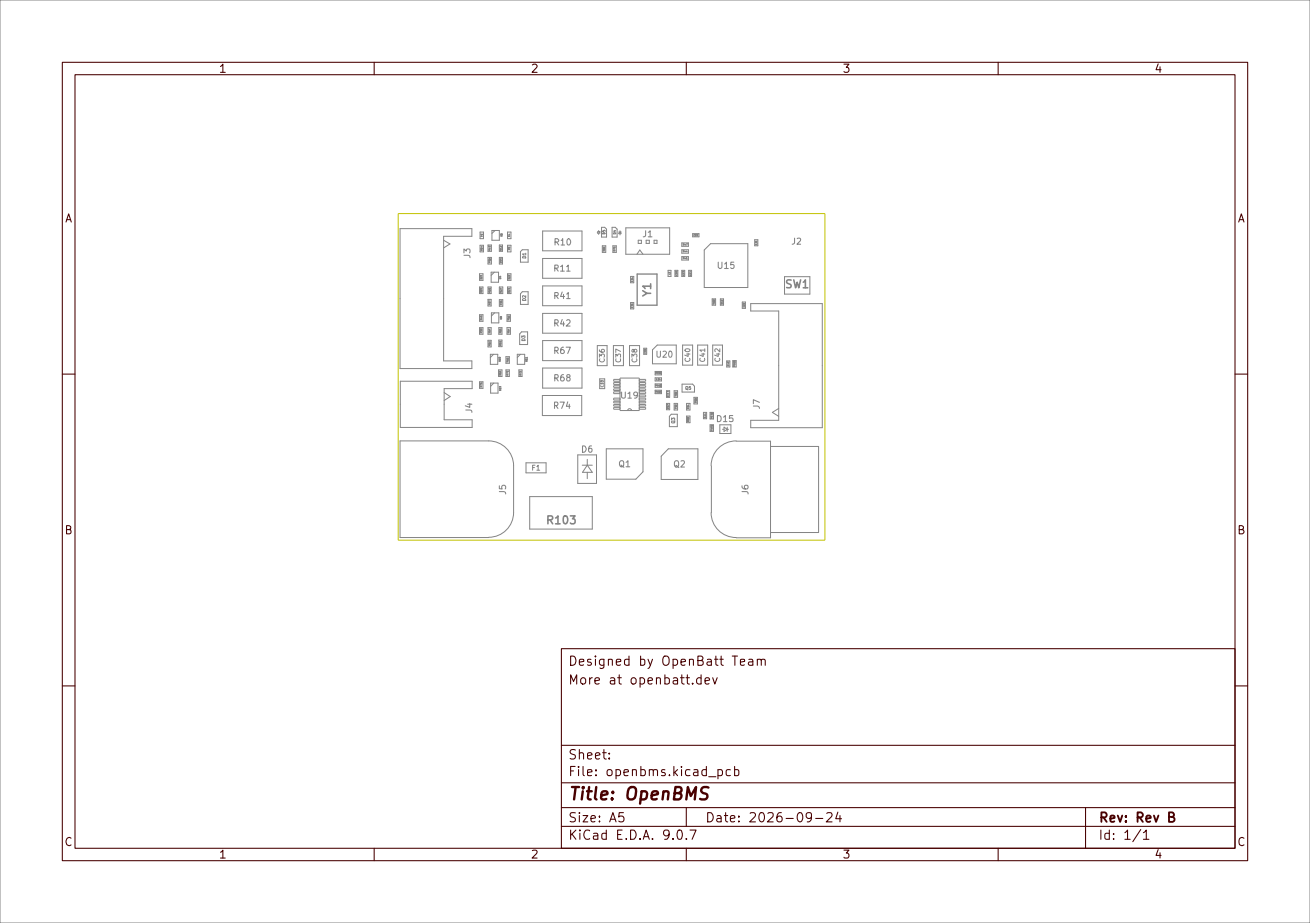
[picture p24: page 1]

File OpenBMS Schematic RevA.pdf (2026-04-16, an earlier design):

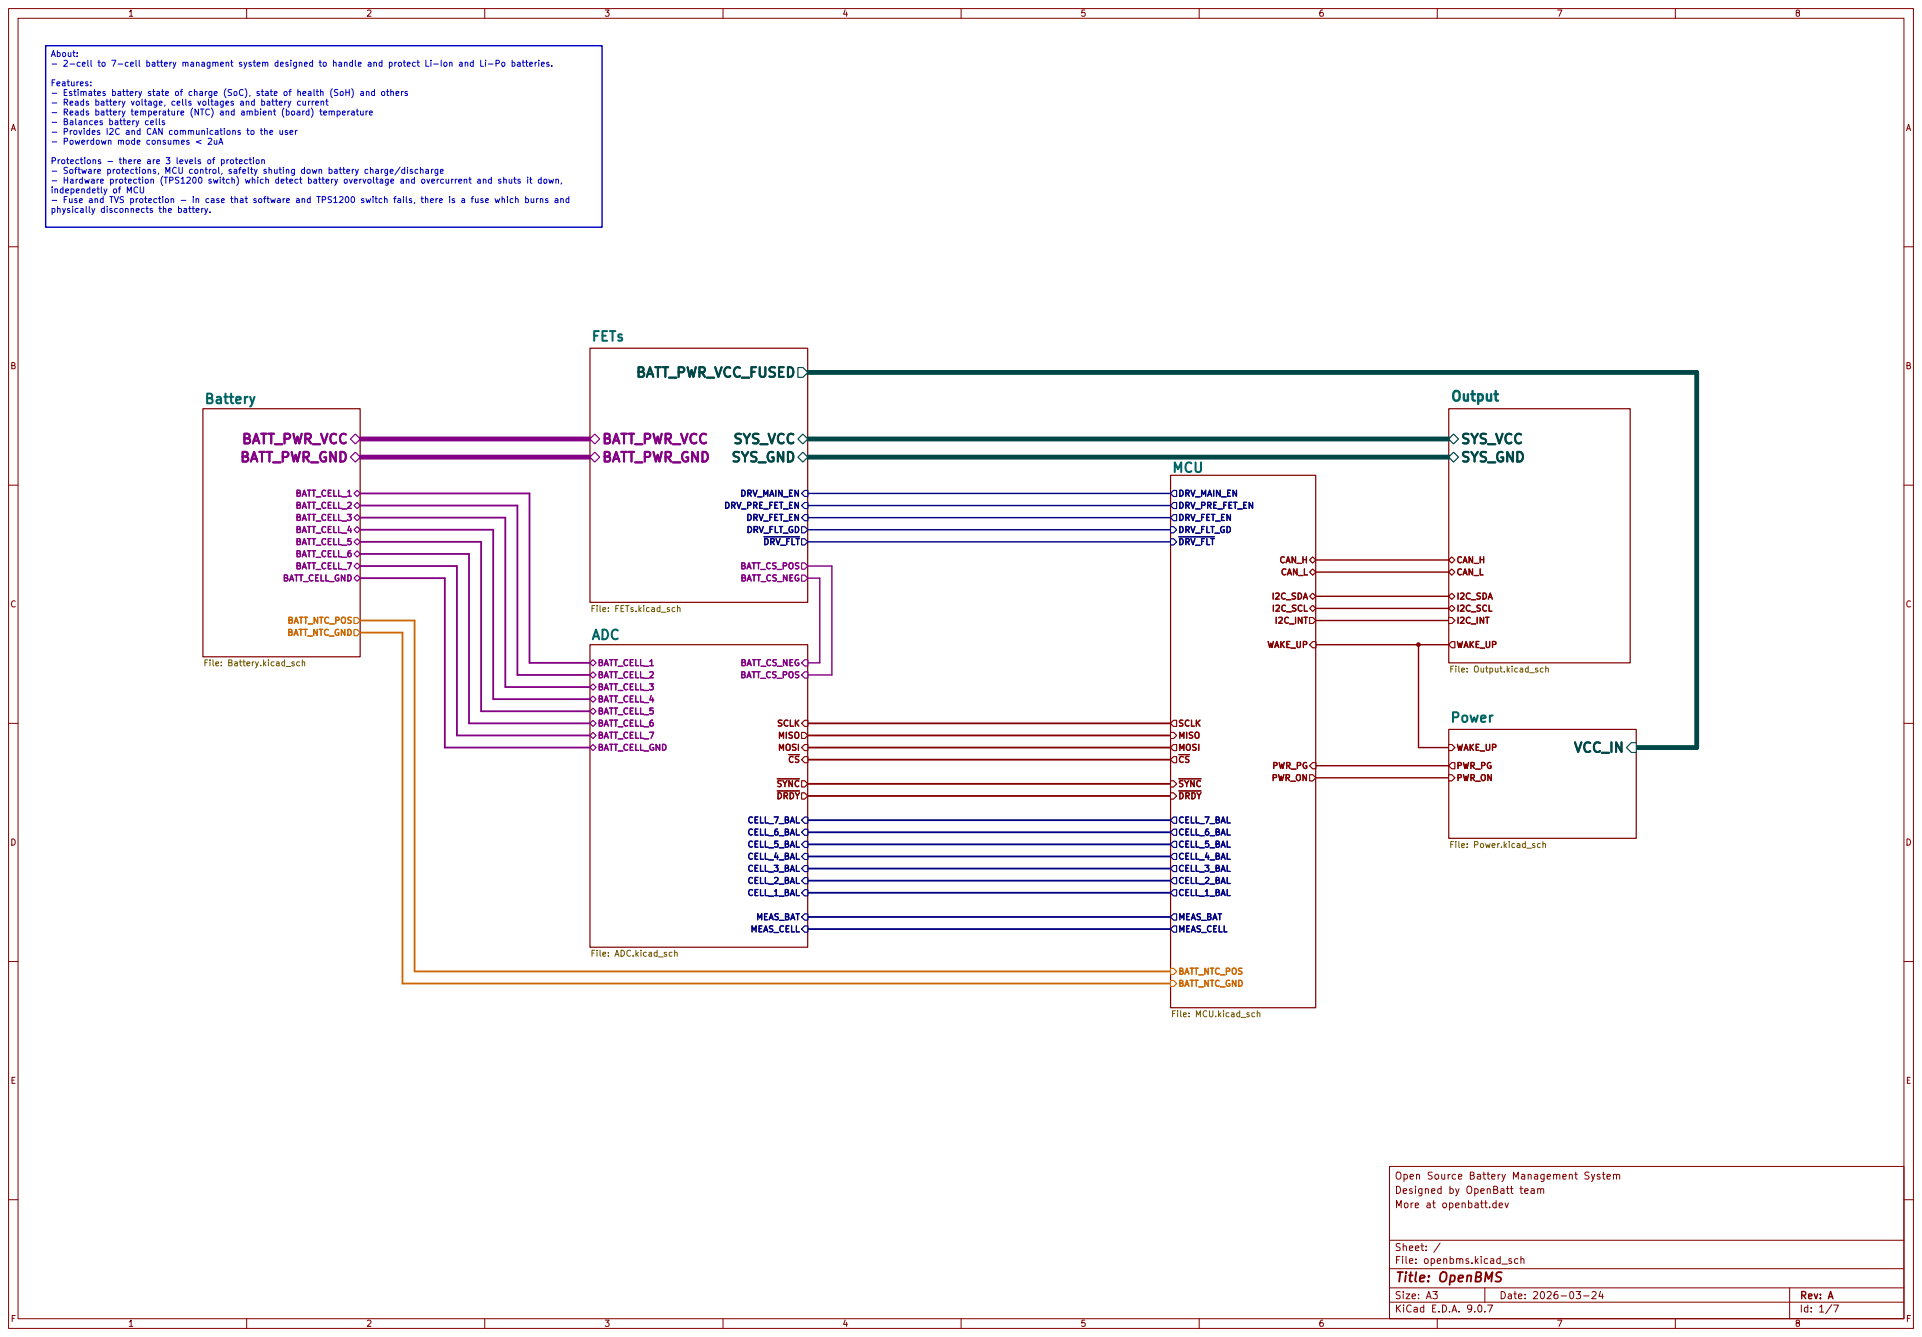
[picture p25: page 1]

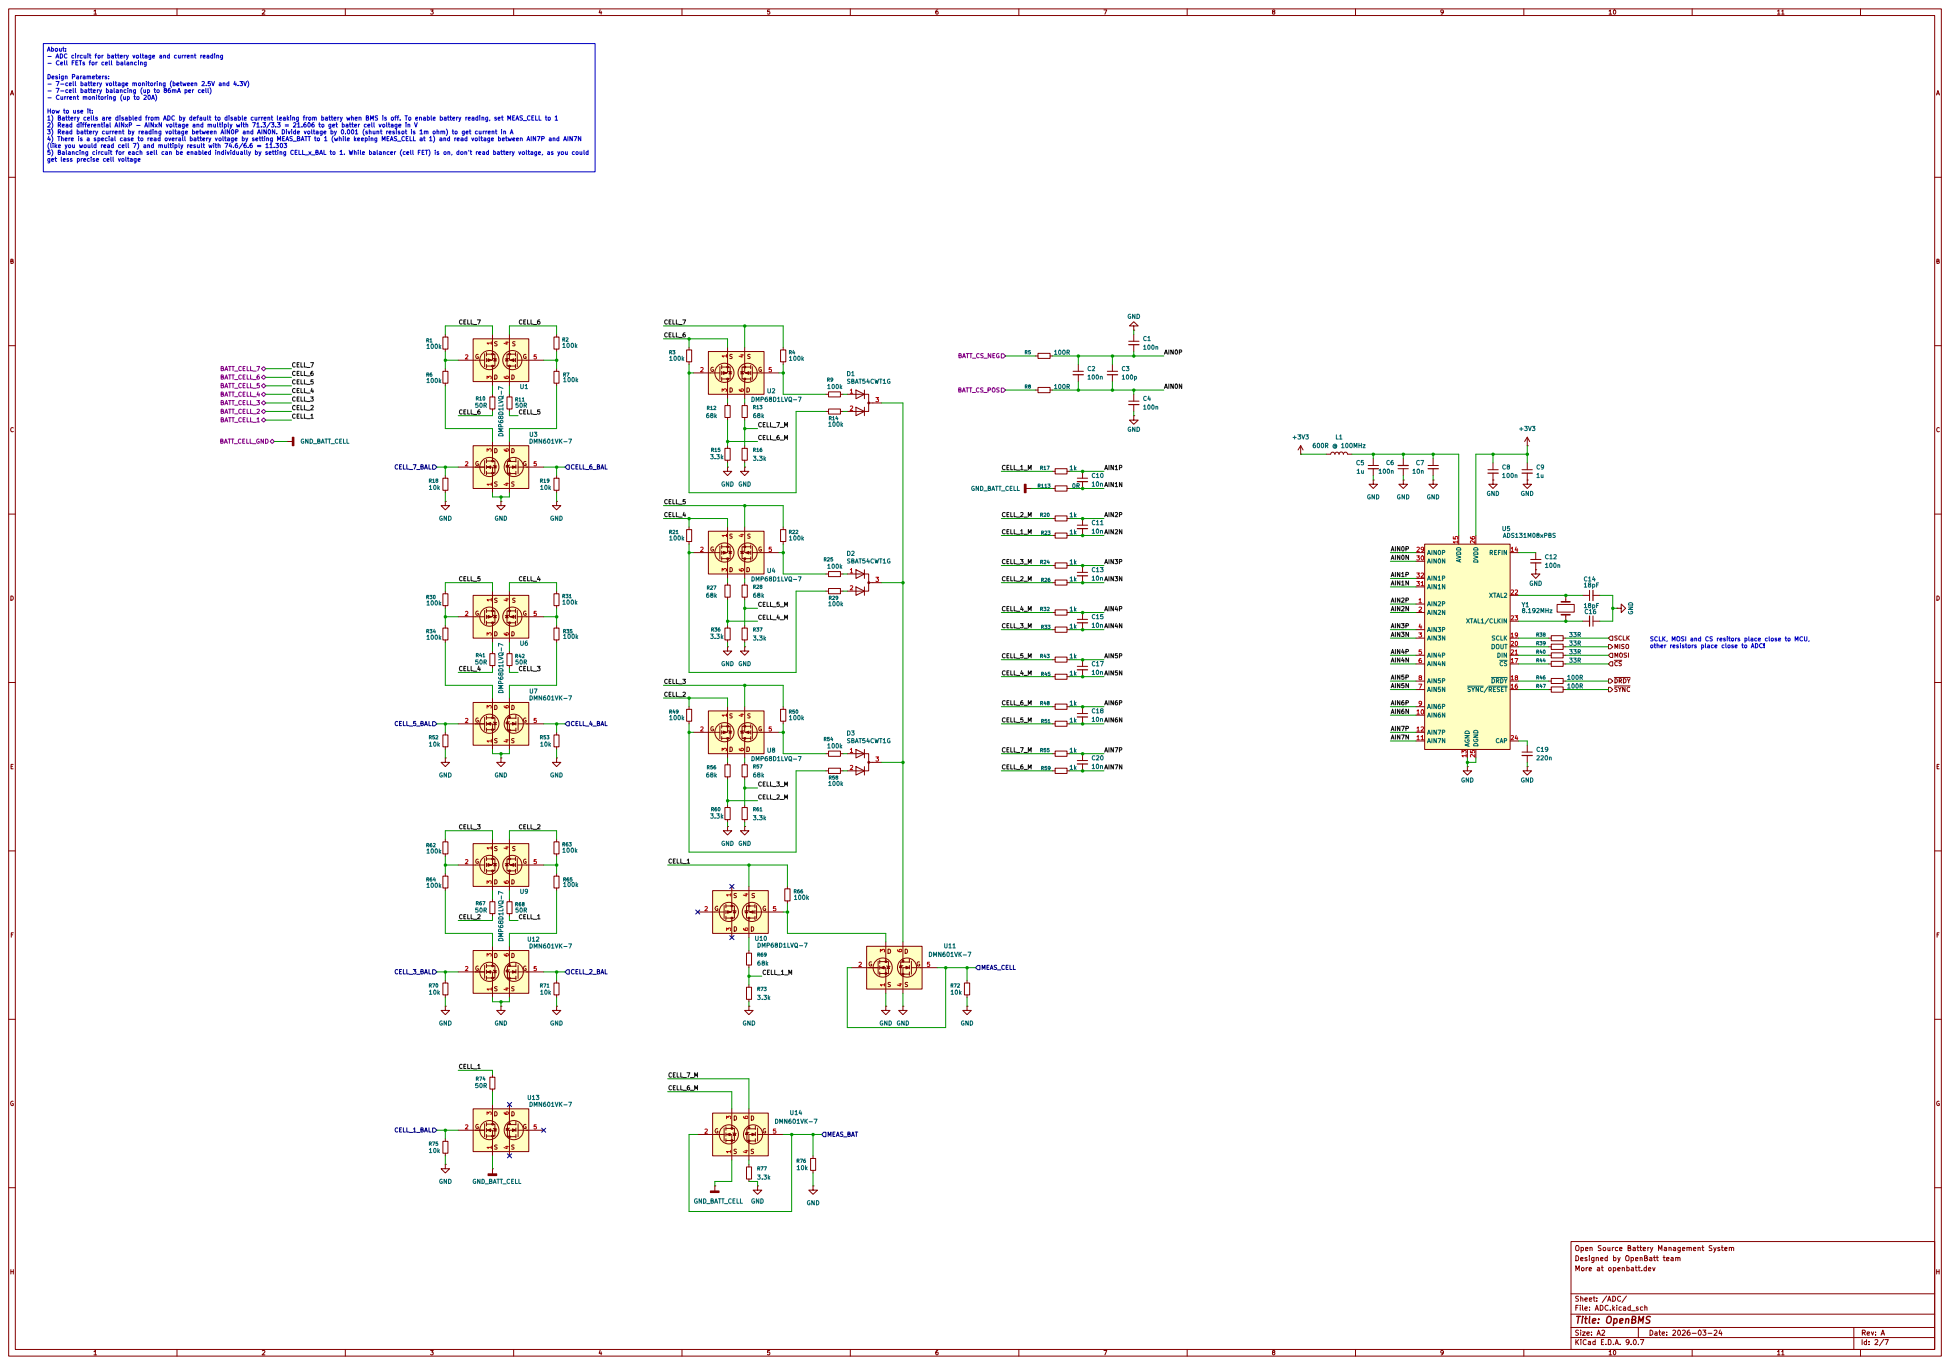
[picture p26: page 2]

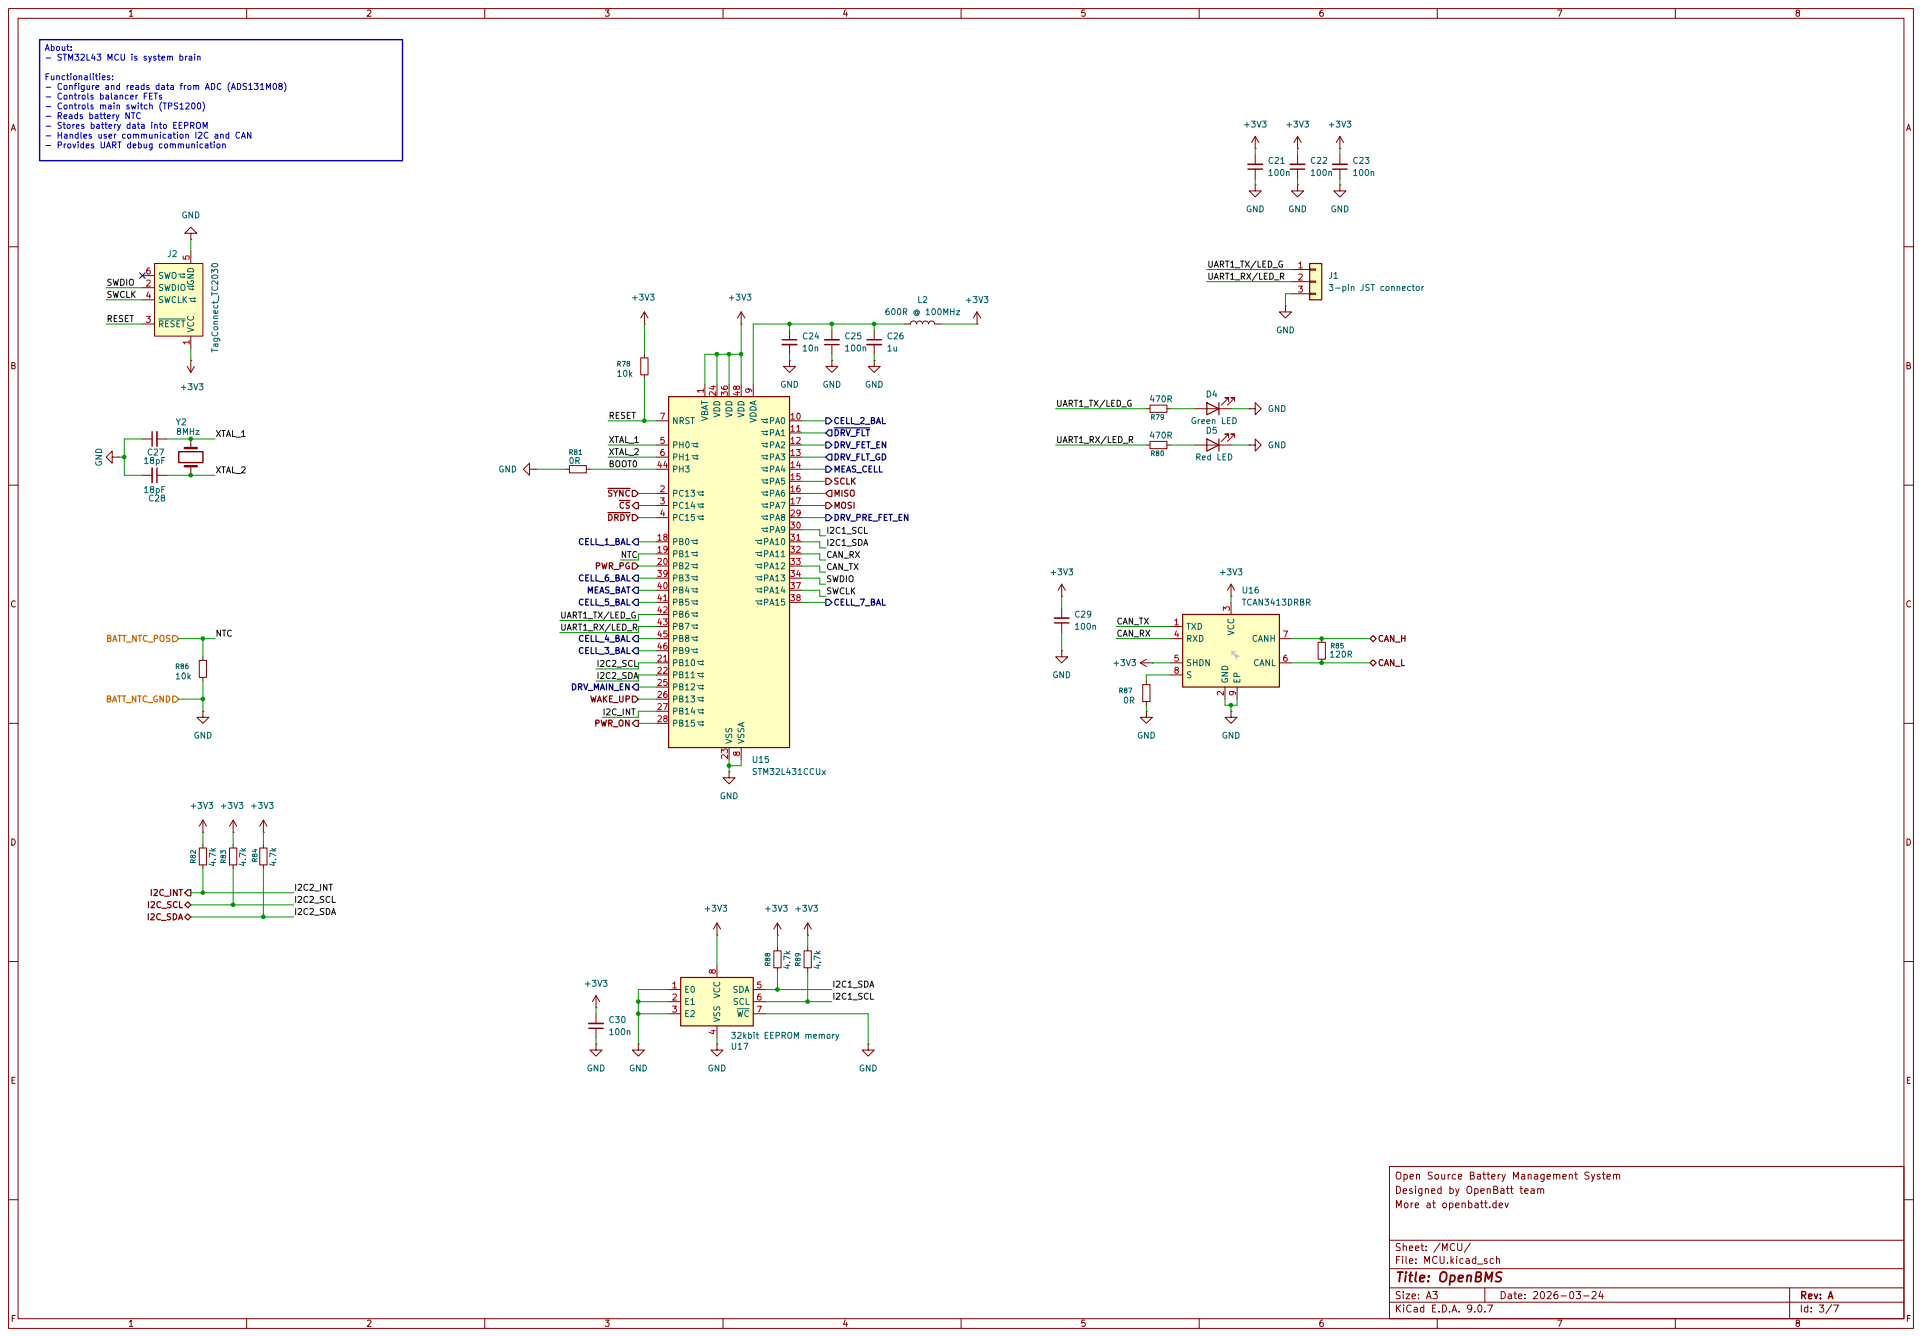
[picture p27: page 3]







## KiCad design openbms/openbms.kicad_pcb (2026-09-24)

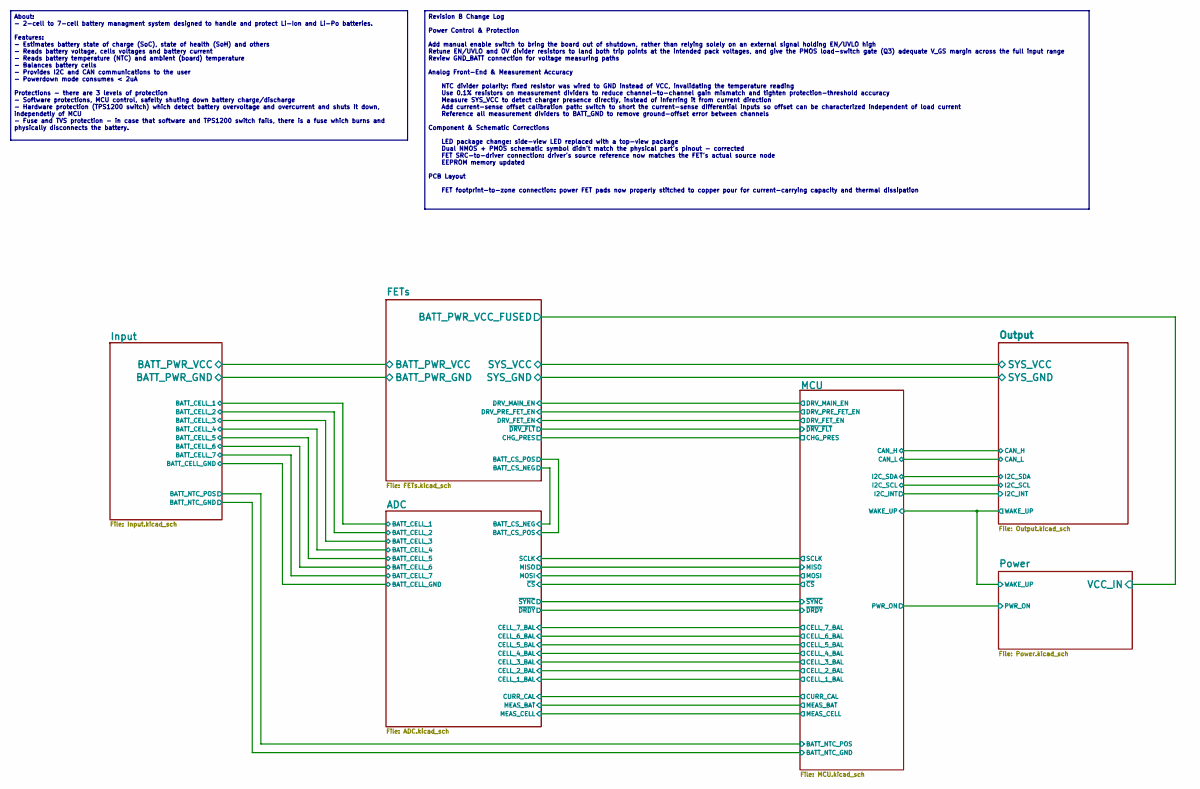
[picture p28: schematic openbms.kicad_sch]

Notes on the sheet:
About: - 2-cell to 7-cell battery managment system designed to handle and protect Li-Ion and Li-Po batteries. Features: - Estimates battery state of charge (SoC), state of health (SoH) and others - Reads battery voltage, cells voltages and battery current - Reads battery temperature (NTC) and ambie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
Revision B Change Log Power Control & Protection Add manual enable switch to bring the board out of shutdown, rather than relying solely on an external signal holding EN/UVLO high Retune EN/UVLO and OV divider resistors to land both trip points at the intended pack voltages, and give the PMOS load-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

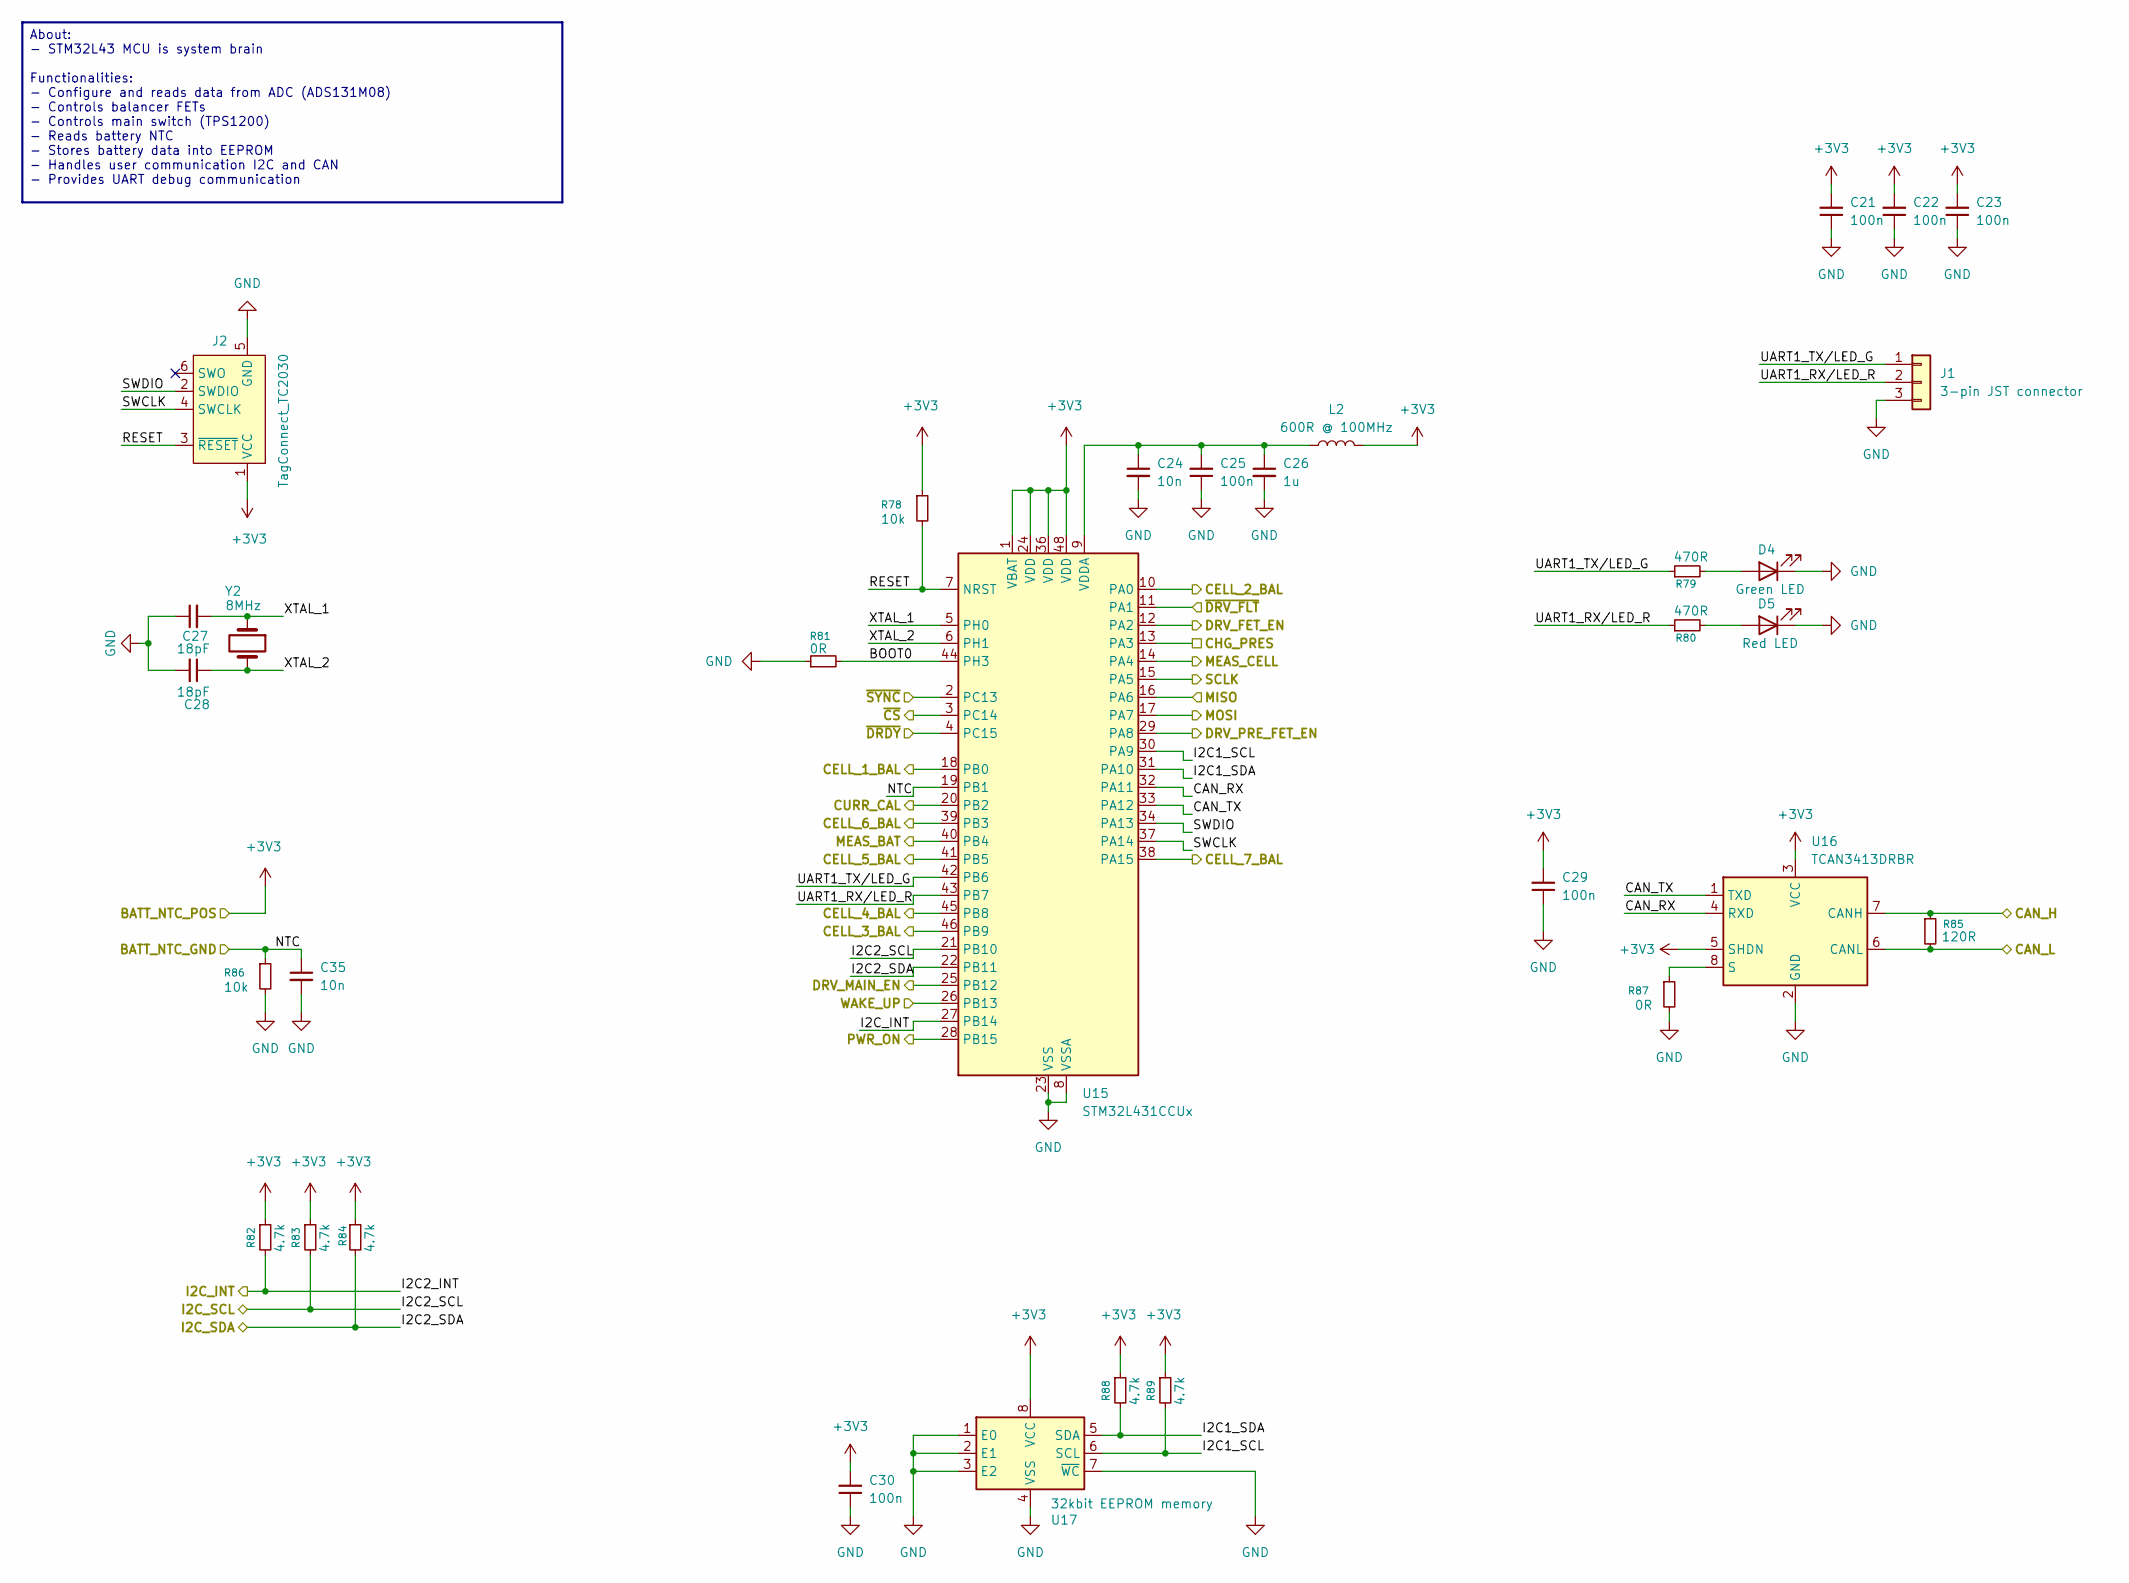
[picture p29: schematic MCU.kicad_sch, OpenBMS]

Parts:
C21, C22, C23, C25, C29, C30: 100n; C_0402_1005Metric; Manufacturer_Part_Number GRM155R71A104KA01D
C24, C35: 10n; C_0402_1005Metric; Manufacturer_Part_Number C0402C103K5REC7411
C26: 1u; C_0402_1005Metric; Manufacturer_Part_Number C0402C105K8PACTU
C27, C28: 18pF; C_0402_1005Metric; Manufacturer_Part_Number GRM1555C1H180JA01D
D4: Green LED; LED_0603_1608Metric; Manufacturer_Part_Number LTST-C190GKT
D5: Red LED; LED_0603_1608Metric; Manufacturer_Part_Number LTST-C190KRKT
J1: 3-pin JST connector; JST_GH_BM03B-GHS-TBT_1x03-1MP_P1.25mm_Vertical; Manufacturer_Part_Number BM03B-GHS-TBT
J2: TagConnect_TC2030; Tag-Connect_TC2030-IDC-FP_2x03_P1.27mm_Vertical
L2: 600R @ 100MHz; L_0402_1005Metric; Manufacturer_Part_Number BLM15PX601SN1D
R78, R86: 10k; R_0402_1005Metric; Manufacturer_Part_Number RMCF0402FT10K0
R79, R80: 470R; R_0402_1005Metric; Manufacturer_Part_Number RC0402FR-07470RL
R81, R87: 0R; R_0402_1005Metric; Manufacturer_Part_Number CR0402AJ/-000GAS
R82, R83, R84, R88, R89: 4.7k; R_0402_1005Metric; Manufacturer_Part_Number RC0402JR-074K7L
R85: 120R; R_0402_1005Metric; Manufacturer_Part_Number CRCW0402120RFKEDC
U15: STM32L431CCUx; QFN-48-1EP_7x7mm_P0.5mm_EP5.6x5.6mm; Manufacturer_Part_Number STM32L431CCU6TR
U16: TCAN3413DRBR; Manufacturer_Part_Number TCAN3413DRBR
U17: 32kbit EEPROM memory; SOIC-8_3.9x4.9mm_P1.27mm; Manufacturer_Part_Number M24256-DRMN8TP/K
Y2: 8MHz; ECS81921230QENTR; Manufacturer_Part_Number ECS-80-12-30Q-DS-TR

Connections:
+3V3: C21.2, C22.2, C23.2, C29.2, C30.2, J2.1 (VCC), L2.2, R78.1, R82.1, R83.1, R84.1, R88.1, R89.1, U15.1 (VBAT), U15.24 (VDD), U15.36 (VDD), U15.48 (VDD), U16.3 (VCC), U16.5 (SHDN), U17.8 (VCC); also elsewhere on the board
/ADC/CELL_1_BAL: U15.18 (PB0); also elsewhere on the board
/ADC/CELL_2_BAL: U15.10 (PA0); also elsewhere on the board
/ADC/CELL_3_BAL: U15.46 (PB9); also elsewhere on the board
/ADC/CELL_4_BAL: U15.45 (PB8); also elsewhere on the board
/ADC/CELL_5_BAL: U15.41 (PB5); also elsewhere on the board
/ADC/CELL_6_BAL: U15.39 (PB3); also elsewhere on the board
/ADC/CELL_7_BAL: U15.38 (PA15); also elsewhere on the board
/ADC/CURR_CAL: U15.20 (PB2); also elsewhere on the board
/ADC/MEAS_BAT: U15.40 (PB4); also elsewhere on the board
/ADC/MEAS_CELL: U15.14 (PA4); also elsewhere on the board
/ADC/MISO: U15.16 (PA6); also elsewhere on the board
/ADC/MOSI: U15.17 (PA7); also elsewhere on the board
/ADC/SCLK: U15.15 (PA5); also elsewhere on the board
/ADC/~CS: U15.3 (PC14); also elsewhere on the board
/ADC/~DRDY: U15.4 (PC15); also elsewhere on the board
/ADC/~SYNC: U15.2 (PC13); also elsewhere on the board
/FETs/CHG_PRES: U15.13 (PA3); also elsewhere on the board
/FETs/DRV_FET_EN: U15.12 (PA2); also elsewhere on the board
/FETs/DRV_MAIN_EN: U15.25 (PB12); also elsewhere on the board
/FETs/DRV_PRE_FET_EN: U15.29 (PA8); also elsewhere on the board
/FETs/~DRV_FLT: U15.11 (PA1); also elsewhere on the board
/MCU/BOOT0: R81.2, U15.44 (PH3)
/MCU/CAN_H: R85.1, U16.7 (CANH); also elsewhere on the board
/MCU/CAN_L: R85.2, U16.6 (CANL); also elsewhere on the board
/MCU/CAN_RX: U15.32 (PA11), U16.4 (RXD)
/MCU/CAN_TX: U15.33 (PA12), U16.1 (TXD)
/MCU/I2C1_SCL: R89.2, U15.30 (PA9), U17.6 (SCL)
/MCU/I2C1_SDA: R88.2, U15.31 (PA10), U17.5 (SDA)
/MCU/I2C2_INT: R82.2, U15.27 (PB14); also elsewhere on the board
/MCU/I2C2_SCL: R83.2, U15.21 (PB10); also elsewhere on the board
/MCU/I2C2_SDA: R84.2, U15.22 (PB11); also elsewhere on the board
/MCU/NTC: C35.1, R86.1, U15.19 (PB1); also elsewhere on the board
/MCU/PWR_ON: U15.28 (PB15); also elsewhere on the board
/MCU/RESET: J2.3 (~RESET), R78.2, U15.7 (NRST)
/MCU/SWCLK: J2.4 (SWCLK), U15.37 (PA14)
/MCU/SWDIO: J2.2 (SWDIO), U15.34 (PA13)
/MCU/WAKE_UP: U15.26 (PB13); also elsewhere on the board
/MCU/XTAL_1: C27.2, U15.5 (PH0), Y2.1
/MCU/XTAL_2: C28.1, U15.6 (PH1), Y2.2
GND: C21.1, C22.1, C23.1, C24.2, C25.1, C26.2, C27.1, C28.2, C29.1, C30.1, C35.2, D4.1 (K), D5.1 (K), J1.3, J2.5 (GND), R81.1, R86.2, R87.2, U15.8 (VSSA), U15.23 (VSS), U15.35 (VSS), U15.47 (VSS), U15.49 (VSS), U16.2 (GND), U17.1 (E0), U17.2 (E1), U17.3 (E2), U17.4 (VSS), U17.7 (~WC); also elsewhere on the board
unnamed: D4.2 (A), R79.2
unnamed: D5.2 (A), R80.2
unnamed: C24.1, C25.2, C26.1, L2.1, U15.9 (VDDA)
unnamed: R87.1, U16.8 (S)

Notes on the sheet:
About: - STM32L43 MCU is system brain Functionalities: - Configure and reads data from ADC (ADS131M08) - Controls balancer FETs - Controls main switch (TPS1200) - Reads battery NTC - Stores battery data into EEPROM - Handles user communication I2C and CAN - Provides UART debug communication

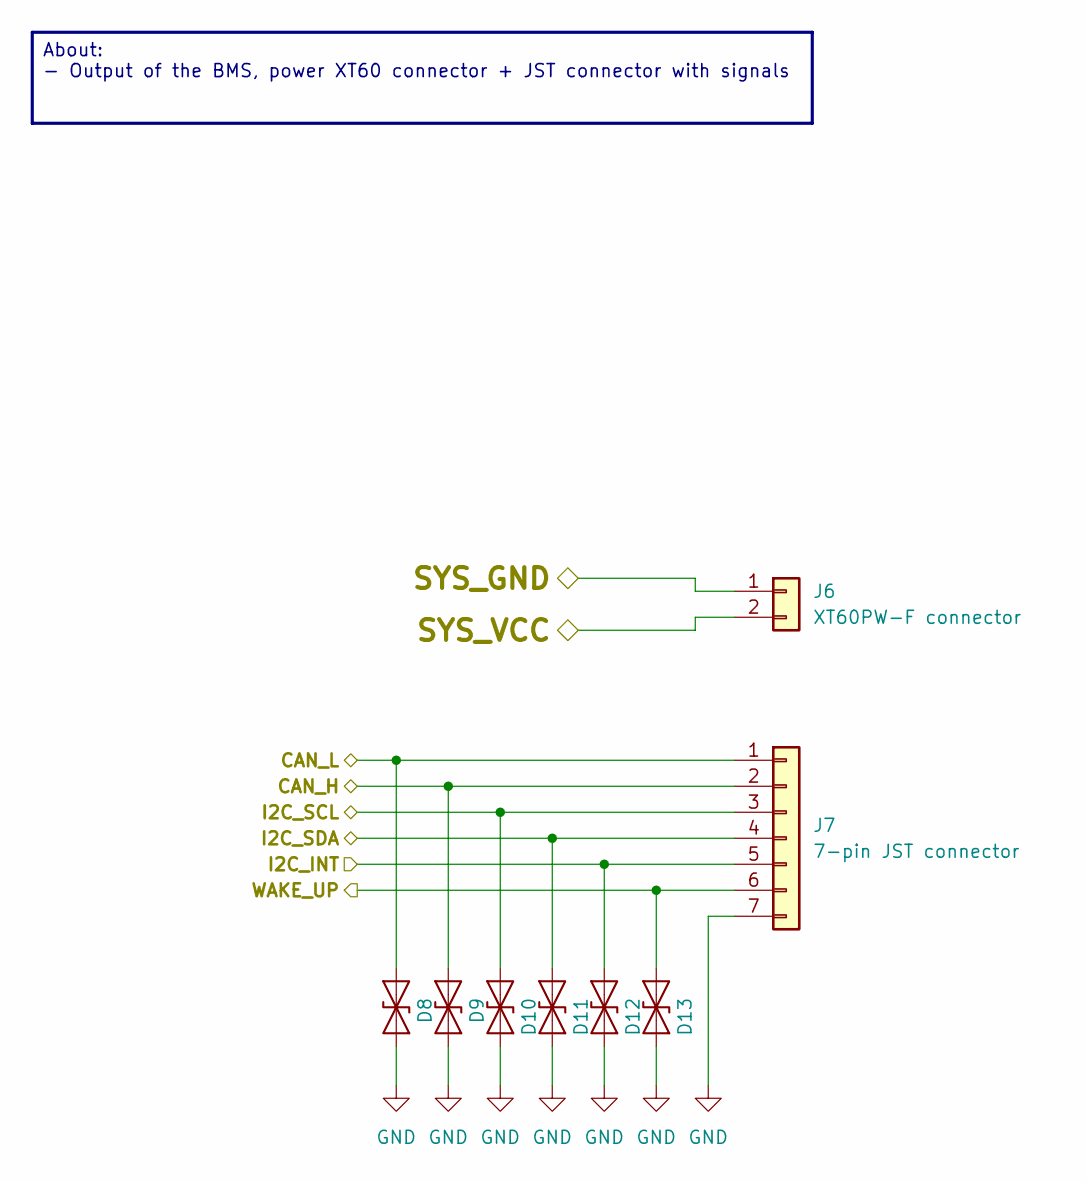
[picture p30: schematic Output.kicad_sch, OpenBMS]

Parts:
D8, D9, D10, D11, D12, D13: TVS diode DBLC03CIQ-7; D_SOD-323; Manufacturer_Part_Number DBLC03CIQ-7
J6: XT60PW-F connector; AMASS_XT60PW-F_1x02_P7.20mm_Horizontal; Manufacturer_Part_Number XT60PW-F
J7: 7-pin JST connector; JST_XH_S7B-XH-A_1x07_P2.50mm_Horizontal; Manufacturer_Part_Number S7B-XH-A

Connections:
/FETs/SYS_VCC: J6.2; also elsewhere on the board
/MCU/CAN_H: D9.1 (A1), J7.2; also elsewhere on the board
/MCU/CAN_L: D8.1 (A1), J7.1; also elsewhere on the board
/MCU/I2C2_INT: D12.1 (A1), J7.5; also elsewhere on the board
/MCU/I2C2_SCL: D10.1 (A1), J7.3; also elsewhere on the board
/MCU/I2C2_SDA: D11.1 (A1), J7.4; also elsewhere on the board
/MCU/WAKE_UP: D13.1 (A1), J7.6; also elsewhere on the board
GND: D8.2 (A2), D9.2 (A2), D10.2 (A2), D11.2 (A2), D12.2 (A2), D13.2 (A2), J7.7; also elsewhere on the board
SYS_GND: J6.1; also elsewhere on the board

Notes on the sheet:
About: - Output of the BMS, power XT60 connector + JST connector with signals

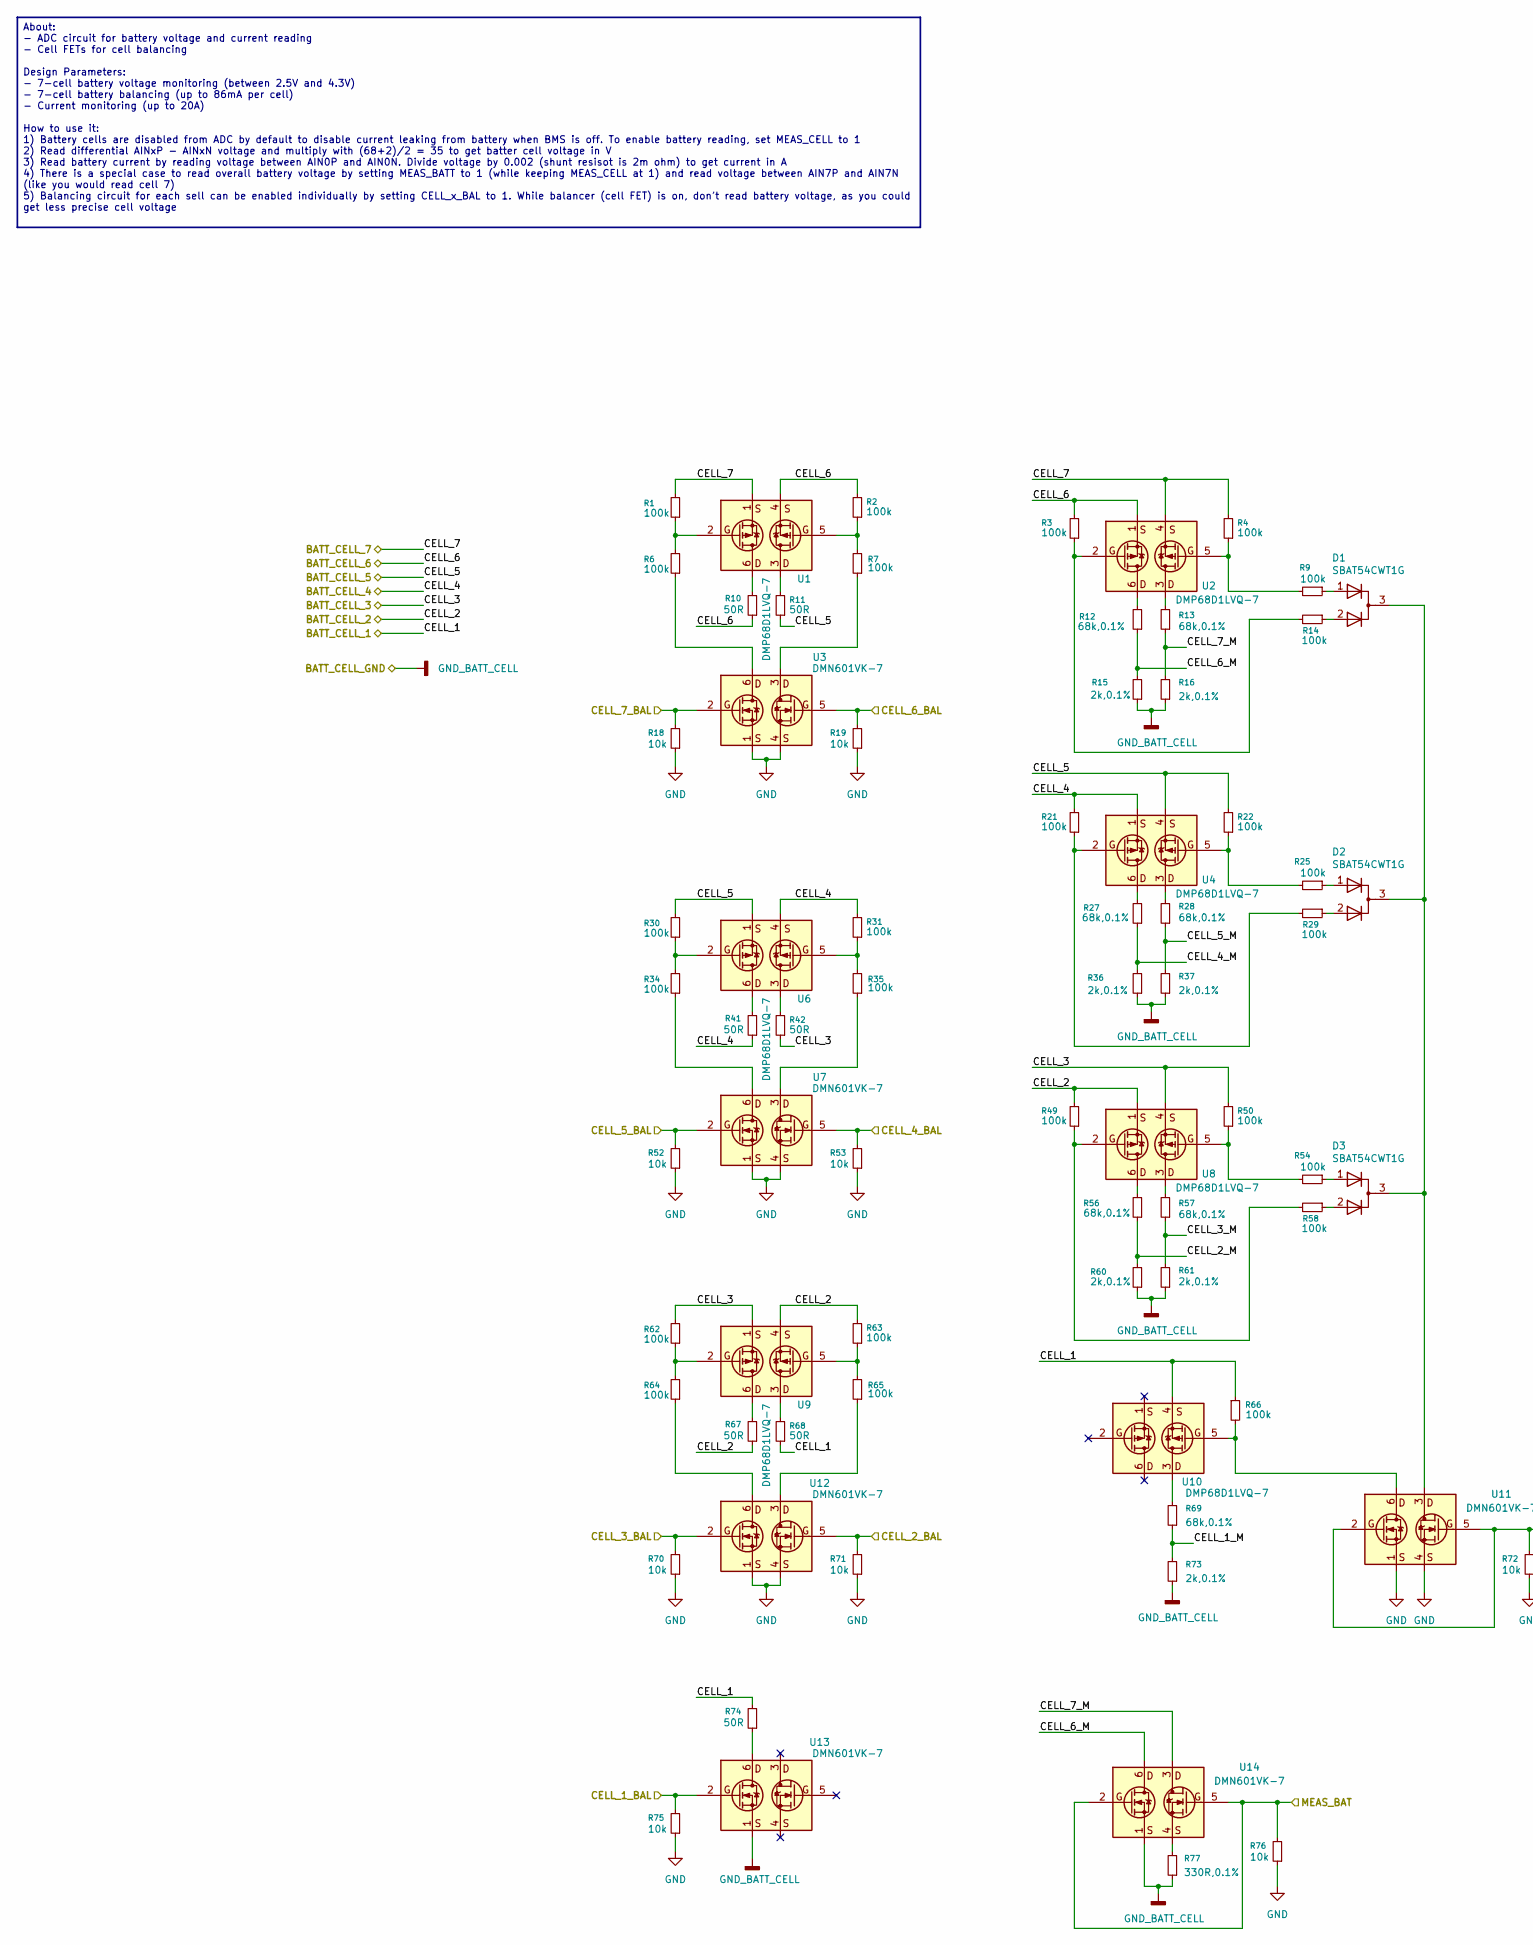
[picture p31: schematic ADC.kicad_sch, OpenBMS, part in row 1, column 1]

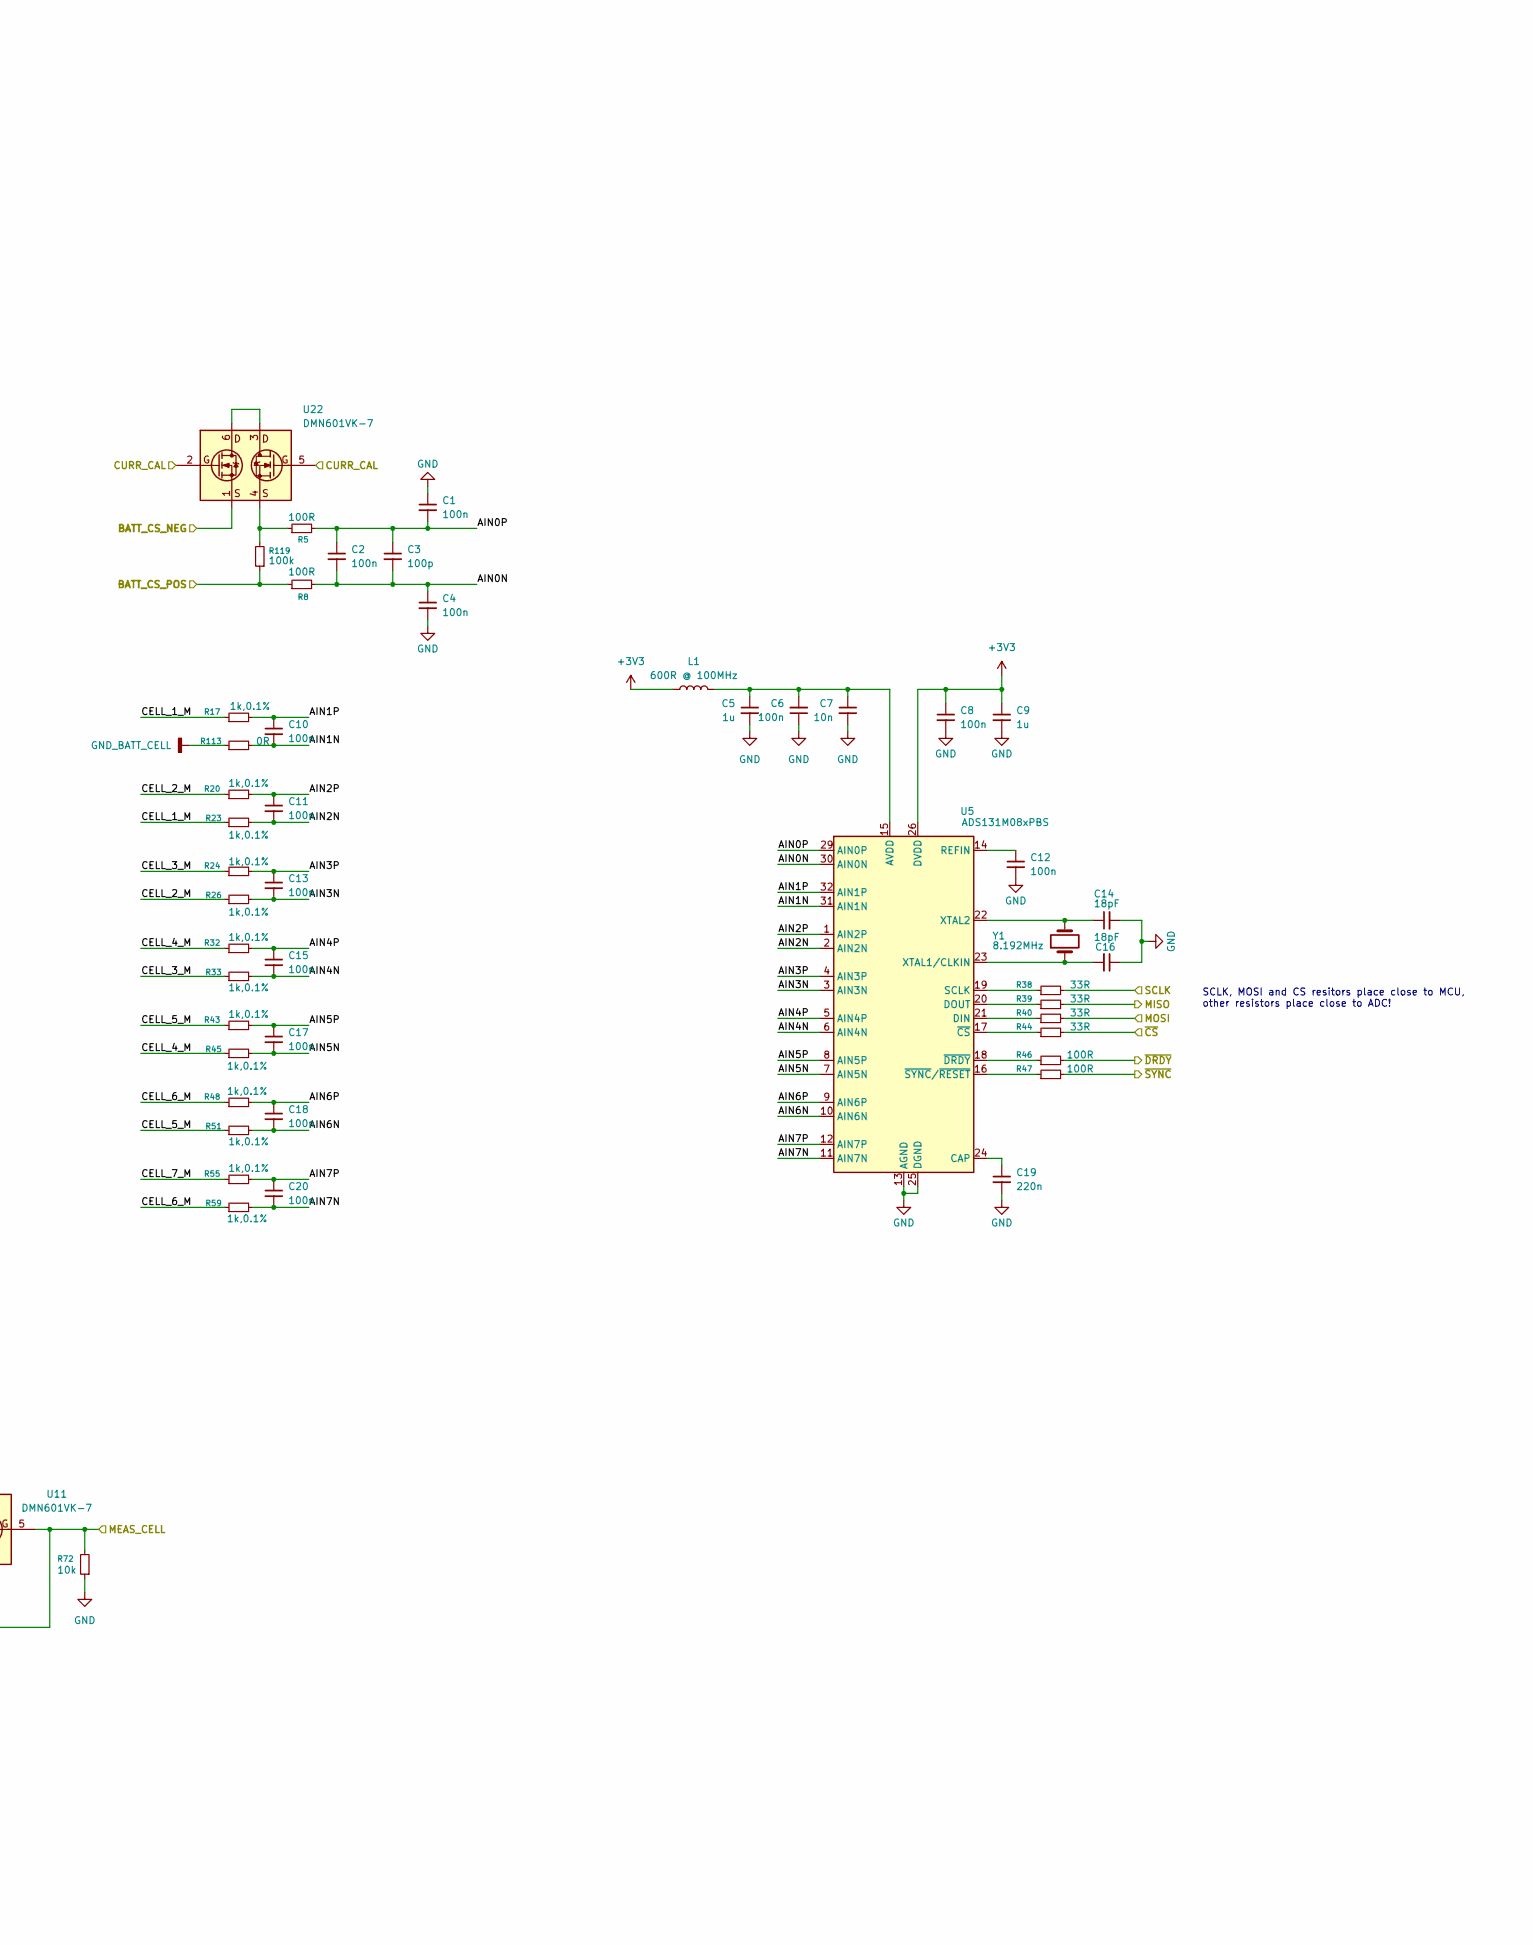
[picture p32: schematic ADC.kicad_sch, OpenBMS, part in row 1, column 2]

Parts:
C1, C2, C4, C6, C8, C10, C11, C12, C13, C15, C17, C18, C20: 100n; C_0402_1005Metric; Manufacturer_Part_Number GRM155R71A104KA01D
C3: 100p; C_0402_1005Metric; Manufacturer_Part_Number CL05C101JB5NNNC
C5, C9: 1u; C_0402_1005Metric; Manufacturer_Part_Number C0402C105K8PACTU
C7: 10n; C_0402_1005Metric; Manufacturer_Part_Number C0402C103K5REC7411
C14, C16: 18pF; C_0402_1005Metric; Manufacturer_Part_Number GRM1555C1H180JA01D
C19: 220n; C_0402_1005Metric; Manufacturer_Part_Number GRM155R71A224KE01J
D1, D2, D3: SBAT54CWT1G; SOT-323_SC-70; Manufacturer_Part_Number SBAT54CWT1G
L1: 600R @ 100MHz; L_0402_1005Metric; Manufacturer_Part_Number BLM15PX601SN1D
R1, R2, R3, R4, R6, R7, R9, R14, R21, R22, R25, R29, R30, R31, R34, R35, R49, R50, R54, R58, R62, R63, R64, R65, R66, R119: 100k; R_0402_1005Metric; Manufacturer_Part_Number RC0402FR-07100KL
R5, R8: 100R; R_0402_1005Metric; Manufacturer_Part_Number RMCF0402FT100R
R10, R11, R41, R42, R67, R68, R74: 50R; R_2512_6332Metric; Manufacturer_Part_Number RNCL2512FT50R0
R12, R13, R27, R28, R56, R57, R69: 68k,0.1%; R_0402_1005Metric; Manufacturer_Part_Number RT0402BRD0768KL
R15, R16, R36, R37, R60, R61, R73: 2k,0.1%; R_0402_1005Metric; Manufacturer_Part_Number RT0402BRD072KL
R17, R20, R23, R24, R26, R32, R33, R43, R45, R48, R51, R55, R59: 1k,0.1%; R_0402_1005Metric; Manufacturer_Part_Number RT0402BRD071KL
R18, R19, R52, R53, R70, R71, R72, R75, R76: 10k; R_0402_1005Metric; Manufacturer_Part_Number RMCF0402FT10K0
R38, R39, R40, R44: 33R; R_0402_1005Metric; Manufacturer_Part_Number RC0402FR-0733RL
R46, R47: 100R; R_0402_1005Metric; Manufacturer_Part_Number RC0402FR-07100RL
R77: 330R,0.1%; R_0402_1005Metric; Manufacturer_Part_Number RT0402BRD07330RL
R113: 0R; R_0402_1005Metric; Manufacturer_Part_Number CR0402AJ/-000GAS
U1, U2, U4, U6, U8, U9, U10: DMP68D1LVQ-7; SOTFL50P162X60-6N; Manufacturer_Part_Number DMP68D1LVQ-7; Mouser Part Number 621-DMP68D1LVQ-7
U3, U7, U11, U12, U13, U14, U22: DMN601VK-7; SOTFL50P162X60-6N; Manufacturer_Part_Number DMN601VK-7
U5: ADS131M08xPBS; TQFP-32_5x5mm_P0.5mm; Manufacturer_Part_Number ADS131M08IPBS
Y1: 8.192MHz; ECS81921230QENTR; Manufacturer_Part_Number ECS-81.92-12-30Q-EN-TR

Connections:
+3V3: C8.1, C9.1, L1.2, U5.26 (DVDD); also elsewhere on the board
/ADC/AIN0N: C2.2, C3.2, C4.1, R8.2, U5.30 (AIN0N)
/ADC/AIN0P: C1.2, C2.1, C3.1, R5.2, U5.29 (AIN0P)
/ADC/AIN1N: C10.2, R113.2, U5.31 (AIN1N)
/ADC/AIN1P: C10.1, R17.2, U5.32 (AIN1P)
/ADC/AIN2N: C11.2, R23.2, U5.2 (AIN2N)
/ADC/AIN2P: C11.1, R20.2, U5.1 (AIN2P)
/ADC/AIN3N: C13.2, R26.2, U5.3 (AIN3N)
/ADC/AIN3P: C13.1, R24.2, U5.4 (AIN3P)
/ADC/AIN4N: C15.2, R33.2, U5.6 (AIN4N)
/ADC/AIN4P: C15.1, R32.2, U5.5 (AIN4P)
/ADC/AIN5N: C17.2, R45.2, U5.7 (AIN5N)
/ADC/AIN5P: C17.1, R43.2, U5.8 (AIN5P)
/ADC/AIN6N: C18.2, R51.2, U5.10 (AIN6N)
/ADC/AIN6P: C18.1, R48.2, U5.9 (AIN6P)
/ADC/AIN7N: C20.2, R59.2, U5.11 (AIN7N)
/ADC/AIN7P: C20.1, R55.2, U5.12 (AIN7P)
/ADC/BATT_CS_POS: R8.1, R119.1; also elsewhere on the board
/ADC/CELL_1: R66.1, R68.1, R74.2, U10.4; also elsewhere on the board
/ADC/CELL_1_BAL: R75.2, U13.2; also elsewhere on the board
/ADC/CELL_1_M: R17.1, R23.1, R69.1, R73.2
/ADC/CELL_2: R49.2, R63.2, R67.1, U8.1, U9.4; also elsewhere on the board
/ADC/CELL_2_BAL: R71.2, U12.5; also elsewhere on the board
/ADC/CELL_2_M: R20.1, R26.1, R56.1, R60.2
/ADC/CELL_3: R42.1, R50.2, R62.2, U8.4, U9.1; also elsewhere on the board
/ADC/CELL_3_BAL: R70.2, U12.2; also elsewhere on the board
/ADC/CELL_3_M: R24.1, R33.1, R57.1, R61.2
/ADC/CELL_4: R21.2, R31.2, R41.1, U4.1, U6.4; also elsewhere on the board
/ADC/CELL_4_BAL: R53.2, U7.5; also elsewhere on the board
/ADC/CELL_4_M: R27.1, R32.1, R36.2, R45.1
/ADC/CELL_5: R11.1, R22.2, R30.2, U4.4, U6.1; also elsewhere on the board
/ADC/CELL_5_BAL: R52.2, U7.2; also elsewhere on the board
/ADC/CELL_5_M: R28.1, R37.2, R43.1, R51.1
/ADC/CELL_6: R2.2, R3.2, R10.1, U1.4, U2.1; also elsewhere on the board
/ADC/CELL_6_BAL: R19.2, U3.5; also elsewhere on the board
/ADC/CELL_6_M: R12.1, R15.2, R48.1, R59.1, U14.6
/ADC/CELL_7: R1.2, R4.2, U1.1, U2.4; also elsewhere on the board
/ADC/CELL_7_BAL: R18.2, U3.2; also elsewhere on the board
/ADC/CELL_7_M: R13.1, R16.2, R55.1, U14.3
/ADC/CURR_CAL: U22.2, U22.5; also elsewhere on the board
/ADC/MEAS_BAT: R76.2, U14.2, U14.5; also elsewhere on the board
/ADC/MEAS_CELL: R72.2, U11.2, U11.5; also elsewhere on the board
/ADC/MISO: R39.2; also elsewhere on the board
/ADC/MOSI: R40.2; also elsewhere on the board
/ADC/SCLK: R38.2; also elsewhere on the board
/ADC/~CS: R44.2; also elsewhere on the board
/ADC/~DRDY: R46.2; also elsewhere on the board
/ADC/~SYNC: R47.2; also elsewhere on the board
GND: C1.1, C4.2, C5.2, C6.1, C7.2, C8.2, C9.2, C12.2, C14.2, C16.1, C19.2, R18.1, R19.1, R52.1, R53.1, R70.1, R71.1, R72.1, R75.1, R76.1, U3.1, U3.4, U5.13 (AGND), U5.25 (DGND), U5.27 (AGND), U5.28 (AGND), U7.1, U7.4, U11.1, U11.4, U12.1, U12.4; also elsewhere on the board
GND_BATT_CELL: R15.1, R16.1, R36.1, R37.1, R60.1, R61.1, R73.1, R77.1, R113.1, U13.1, U14.1; also elsewhere on the board
unnamed: D1.1 (A), R9.1
unnamed: D1.2 (A), R14.1
unnamed: D1.3 (K), D2.3 (K), D3.3 (K), U11.3
unnamed: D2.1 (A), R25.1
unnamed: D2.2 (A), R29.1
unnamed: D3.1 (A), R54.1
unnamed: D3.2 (A), R58.1
unnamed: R1.1, R6.2, U1.2
unnamed: R2.1, R7.2, U1.5
unnamed: R4.1, R9.2, U2.5
unnamed: R6.1, U3.6
unnamed: R7.1, U3.3
unnamed: R10.2, U1.6
unnamed: R11.2, U1.3
unnamed: R12.2, U2.6
unnamed: R13.2, U2.3
unnamed: R3.1, R14.2, U2.2
unnamed: R21.1, R29.2, U4.2
unnamed: R22.1, R25.2, U4.5
unnamed: R27.2, U4.6
unnamed: R28.2, U4.3
unnamed: R30.1, R34.2, U6.2
unnamed: R31.1, R35.2, U6.5
unnamed: R34.1, U7.6
unnamed: R35.1, U7.3
unnamed: R41.2, U6.6
unnamed: R42.2, U6.3
unnamed: R49.1, R58.2, U8.2
unnamed: R50.1, R54.2, U8.5
unnamed: R56.2, U8.6
unnamed: R57.2, U8.3
unnamed: R62.1, R64.2, U9.2
unnamed: R63.1, R65.2, U9.5
unnamed: R64.1, U12.6
unnamed: R65.1, U12.3
unnamed: R66.2, U10.5, U11.6
unnamed: R67.2, U9.6
unnamed: R68.2, U9.3
unnamed: R69.2, U10.3
unnamed: R74.1, U13.6
unnamed: R77.2, U14.4
unnamed: R5.1, R119.2, U22.4
unnamed: C5.1, C6.2, C7.1, L1.1, U5.15 (AVDD)
unnamed: C19.1, U5.24 (CAP)
unnamed: R40.1, U5.21 (DIN)
unnamed: R39.1, U5.20 (DOUT)
unnamed: C12.1, U5.14 (REFIN)
unnamed: R38.1, U5.19 (SCLK)
unnamed: C16.2, U5.23 (XTAL1/CLKIN), Y1.1
unnamed: C14.1, U5.22 (XTAL2), Y1.2
unnamed: R44.1, U5.17 (~CS)
unnamed: R46.1, U5.18 (~DRDY)
unnamed: R47.1, U5.16 (~SYNC/~RESET)
unnamed: U22.3, U22.6
SYS_GND: U22.1; also elsewhere on the board

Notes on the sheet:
SCLK, MOSI and CS resitors place close to MCU, other resistors place close to ADC!
About: - ADC circuit for battery voltage and current reading - Cell FETs for cell balancing Design Parameters: - 7-cell battery voltage monitoring (between 2.5V and 4.3V) - 7-cell battery balancing (up to 86mA per cell) - Current monitoring (up to 20A) How to use it: 1) Battery cells are disabled f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

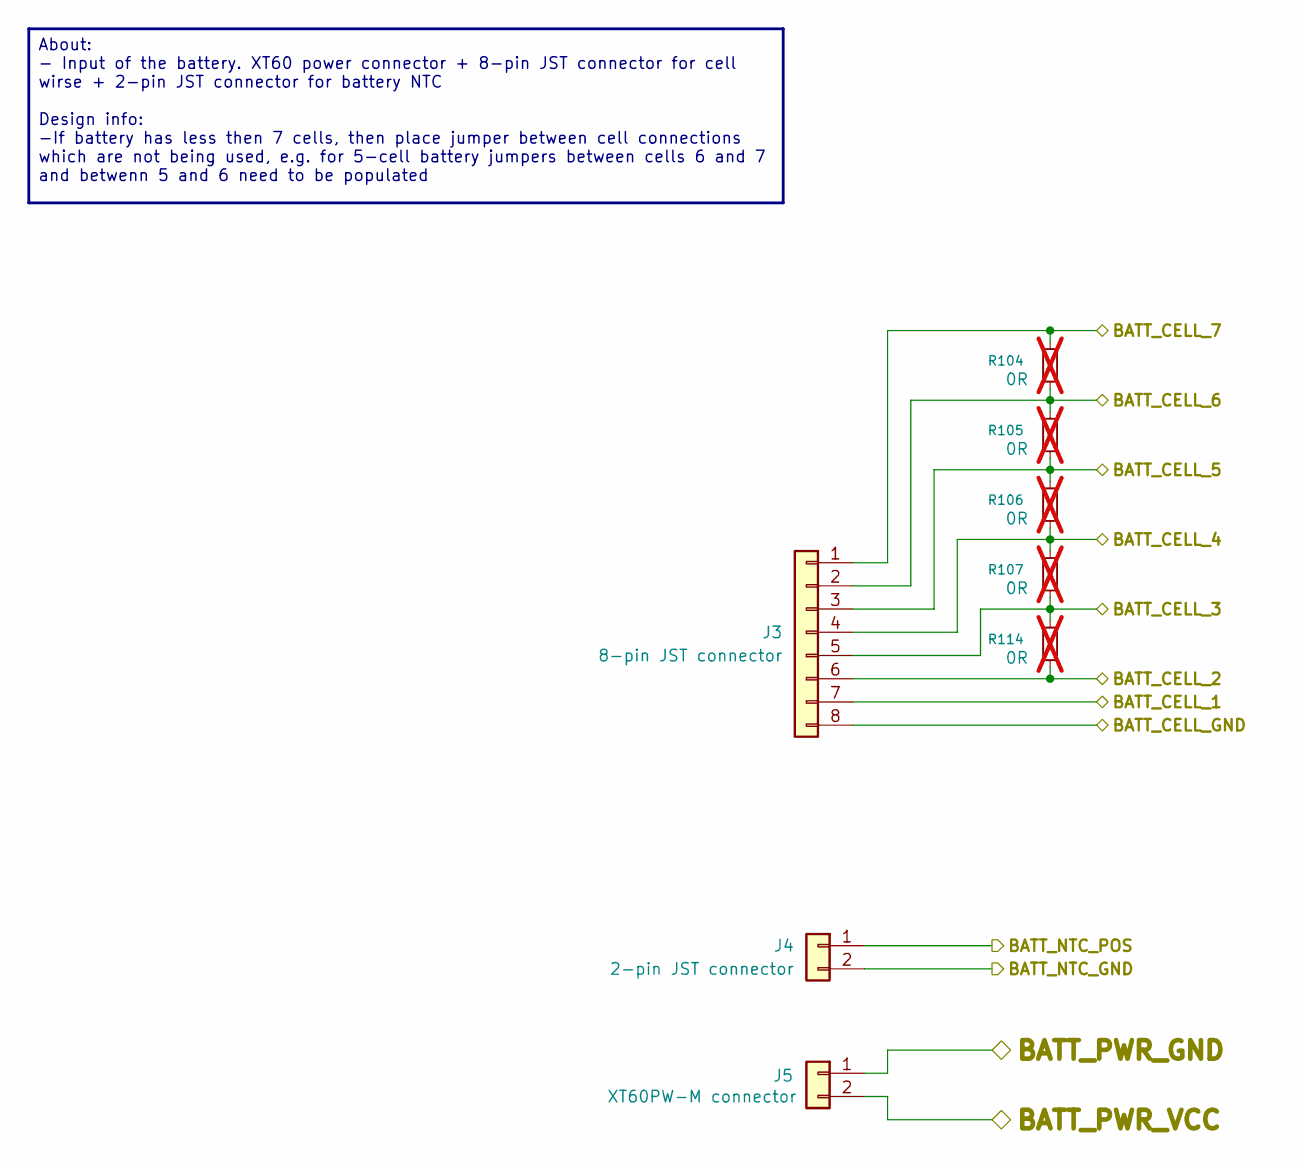
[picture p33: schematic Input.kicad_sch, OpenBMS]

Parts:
J3: 8-pin JST connector; JST_XH_S8B-XH-A_1x08_P2.50mm_Horizontal; Manufacturer_Part_Number S8B-XH-A
J4: 2-pin JST connector; JST_XH_S2B-XH-A_1x02_P2.50mm_Horizontal; Manufacturer_Part_Number S2B-XH-A
J5: XT60PW-M connector; AMASS_XT60PW-M_1x02_P7.20mm_Horizontal; Manufacturer_Part_Number XT60PW-M
R104, R105, R106, R107, R114: 0R; R_0402_1005Metric; Manufacturer_Part_Number CR0402AJ/-000GAS; not fitted

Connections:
+3V3: J4.1; also elsewhere on the board
/ADC/BATT_CS_POS: J5.1; also elsewhere on the board
/ADC/CELL_1: J3.7; also elsewhere on the board
/ADC/CELL_2: J3.6, R114.2; also elsewhere on the board
/ADC/CELL_3: J3.5, R107.2, R114.1; also elsewhere on the board
/ADC/CELL_4: J3.4, R106.2, R107.1; also elsewhere on the board
/ADC/CELL_5: J3.3, R105.2, R106.1; also elsewhere on the board
/ADC/CELL_6: J3.2, R104.2, R105.1; also elsewhere on the board
/ADC/CELL_7: J3.1, R104.1; also elsewhere on the board
/FETs/BATT_PWR_VCC: J5.2; also elsewhere on the board
/MCU/NTC: J4.2; also elsewhere on the board
GND_BATT_CELL: J3.8; also elsewhere on the board

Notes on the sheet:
About: - Input of the battery. XT60 power connector + 8-pin JST connector for cell wirse + 2-pin JST connector for battery NTC Design info: -If battery has less then 7 cells, then place jumper between cell connections which are not being used, e.g. for 5-cell battery jumpers between cells 6 and 7 a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

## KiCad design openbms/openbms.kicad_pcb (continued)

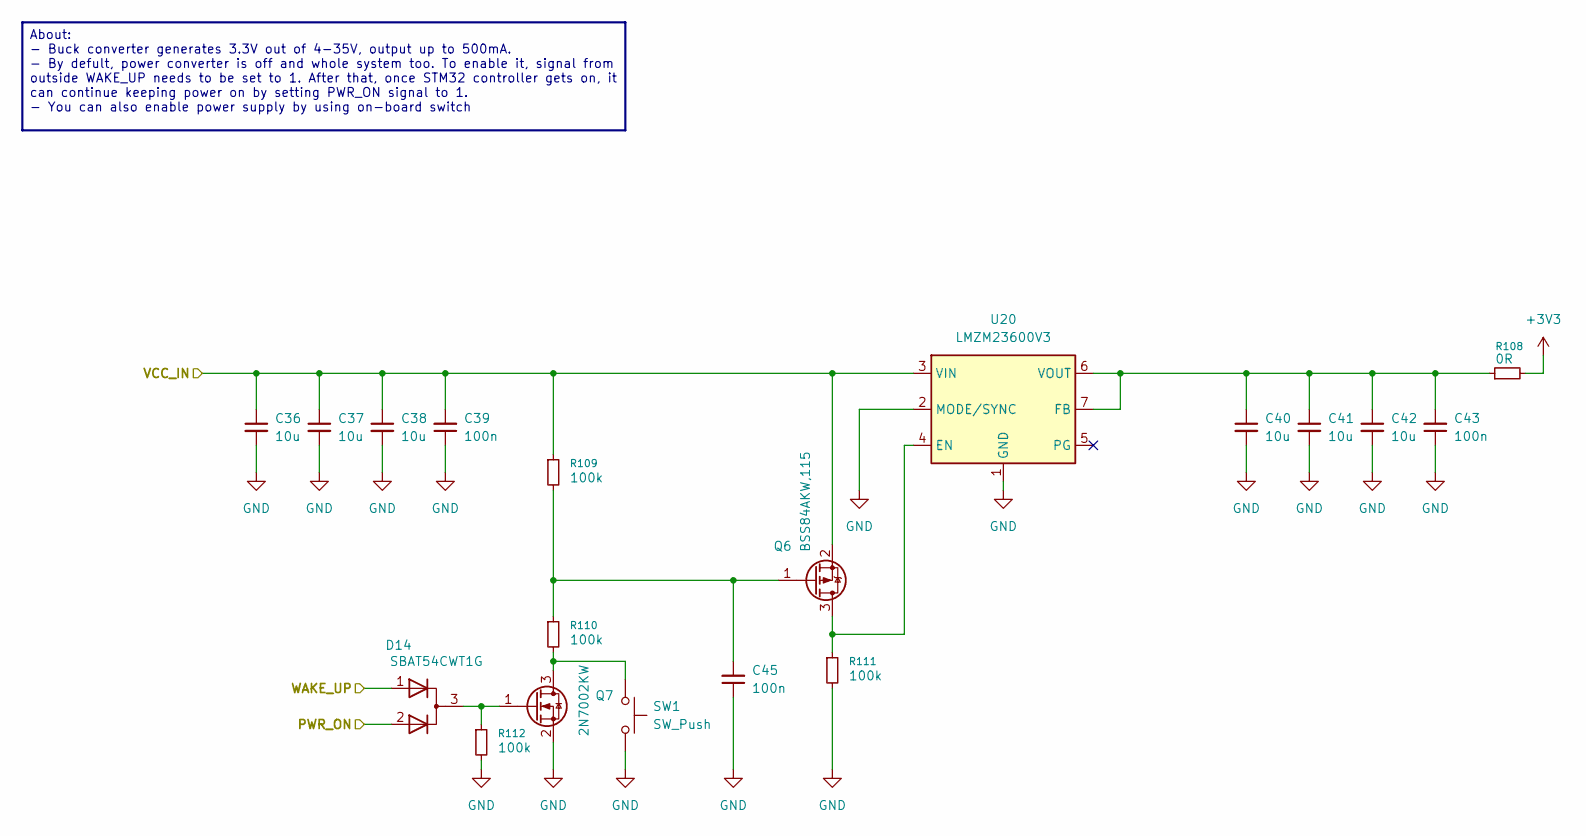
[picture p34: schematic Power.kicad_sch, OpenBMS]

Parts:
C36, C37, C38, C40, C41, C42: 10u; C_1206_3216Metric; Manufacturer_Part_Number CL31A106MBHNNNE
C39, C43, C45: 100n; C_0402_1005Metric; Manufacturer_Part_Number GRM155R71A104KA01D
D14: SBAT54CWT1G; SOT-323_SC-70; Manufacturer_Part_Number SBAT54CWT1G
Q6: BSS84AKW,115; SOT-323_SC-70; Manufacturer_Part_Number BSS84AKW,115
Q7: 2N7002KW; SOT-323_SC-70; Manufacturer_Part_Number 2N7002KW
R108: 0R; R_0402_1005Metric; Manufacturer_Part_Number CR0402AJ/-000GAS
R109, R110, R111, R112: 100k; R_0402_1005Metric; Manufacturer_Part_Number RC0402FR-07100KL
SW1: SW_Push; 435451019820; Manufacturer_Part_Number 435451019820
U20: LMZM23600V3; Texas_SIL0010A_MicroSiP-10-1EP_3.8x3mm_P0.6mm_EP0.7x2.9mm_T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; Manufacturer_Part_Number LMZM23600V3SILR

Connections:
+3V3: R108.2; also elsewhere on the board
/FETs/BATT_PWR_VCC_FUSED: C36.1, C37.1, C38.1, C39.2, Q6.2 (S), R109.1, U20.3 (VIN); also elsewhere on the board
/MCU/PWR_ON: D14.2 (A); also elsewhere on the board
/MCU/WAKE_UP: D14.1 (A); also elsewhere on the board
GND: C36.2, C37.2, C38.2, C39.1, C40.2, C41.2, C42.2, C43.1, C45.1, Q7.2 (S), R111.2, R112.2, SW1.2, U20.1 (GND), U20.2 (MODE/SYNC), U20.11 (GND); also elsewhere on the board
unnamed: D14.3 (K), Q7.1 (G), R112.1
unnamed: Q6.3 (D), R111.1, U20.4 (EN)
unnamed: C45.2, Q6.1 (G), R109.2, R110.1
unnamed: Q7.3 (D), R110.2, SW1.1
unnamed: C40.1, C41.1, C42.1, C43.2, R108.1, U20.6 (VOUT), U20.7 (FB)

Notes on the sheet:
About: - Buck converter generates 3.3V out of 4-35V, output up to 500mA. - By defult, power converter is off and whole system too. To enable it, signal from outside WAKE_UP needs to be set to 1. After that, once STM32 controller gets on, it can continue keeping power on by setting PWR_ON signal to 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

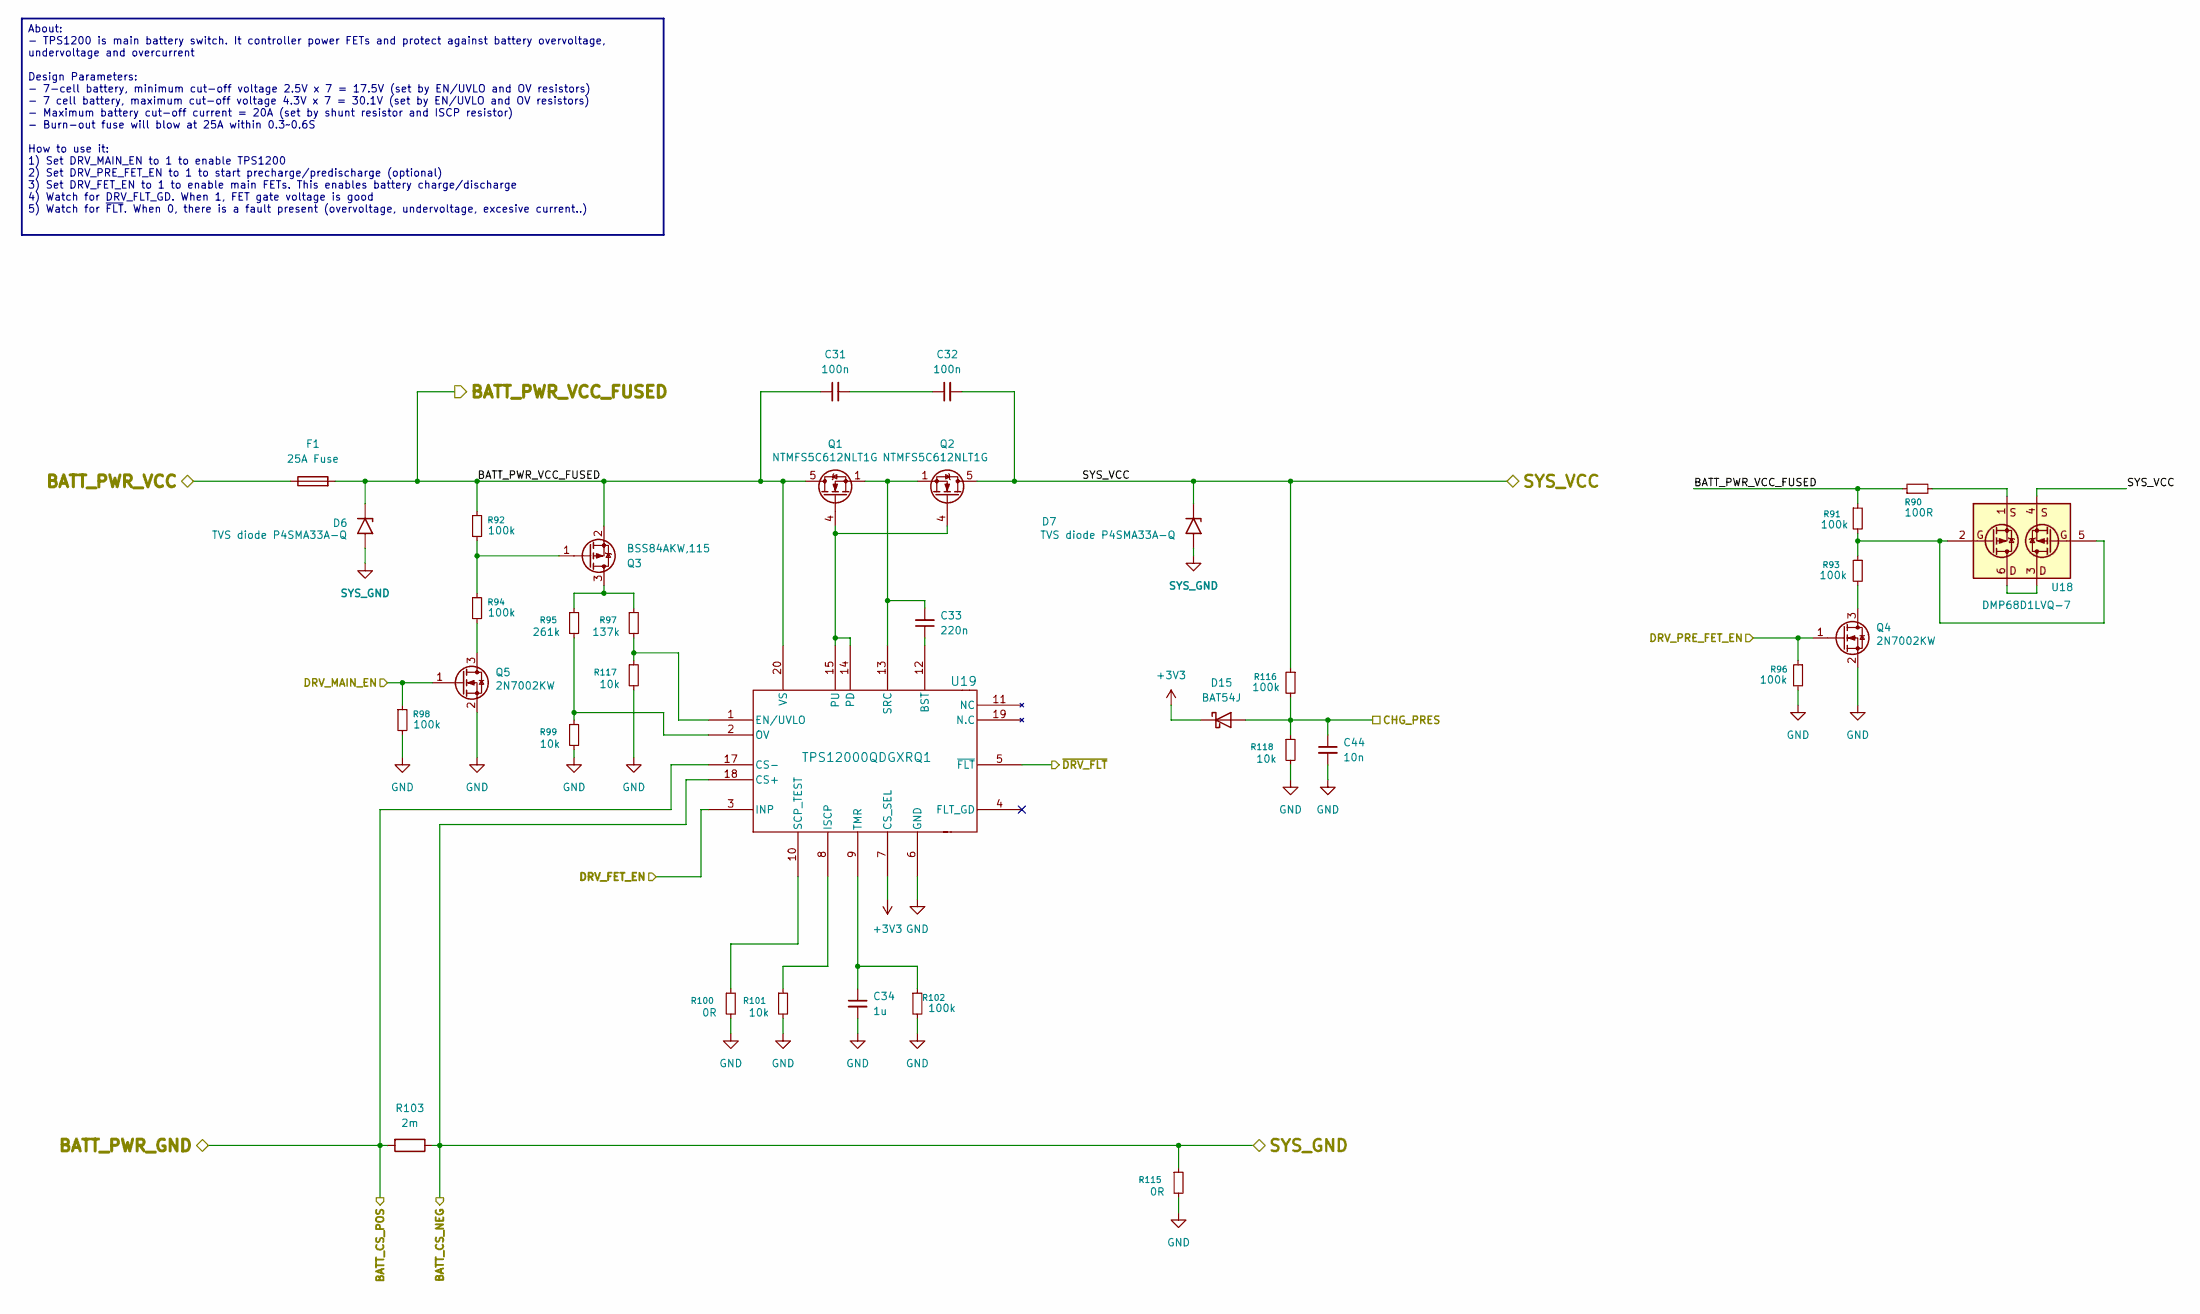
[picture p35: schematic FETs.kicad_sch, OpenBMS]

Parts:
C31, C32: 100n; C_0402_1005Metric; Manufacturer_Part_Number GRM155R71A104KA01D
C33: 220n; C_0603_1608Metric; Manufacturer_Part_Number CL10E224KA84PNC
C34: 1u; C_0402_1005Metric; Manufacturer_Part_Number C0402C105K8PACTU
C44: 10n; C_0402_1005Metric; Manufacturer_Part_Number C0402C103K5REC7411
D6, D7: TVS diode P4SMA33A-Q; D_SMA; Manufacturer_Part_Number P4SMA33A-Q
D15: BAT54J; D_SOD-323F
F1: 25A Fuse; Fuse_1206_3216Metric; Manufacturer_Part_Number SF-1206HV25M-2
Q1, Q2: NTMFS5C612NLT1G; ONSemi_SO-8FL_488AA; Manufacturer_Part_Number NTMFS5C612NLT1G
Q3: BSS84AKW,115; SOT-323_SC-70; Manufacturer_Part_Number BSS84AKW,115
Q4, Q5: 2N7002KW; SOT-323_SC-70; Manufacturer_Part_Number 2N7002KW
R90: 100R; R_2512_6332Metric; Manufacturer_Part_Number 3521100RFT
R91, R92, R93, R94, R96, R98, R102, R116: 100k; R_0402_1005Metric; Manufacturer_Part_Number RC0402FR-07100KL
R95: 261k; R_0402_1005Metric; Manufacturer_Part_Number RC0402FR-07261KL
R97: 137k; R_0402_1005Metric; Manufacturer_Part_Number RC0402FR-07137KL
R99, R101, R117, R118: 10k; R_0402_1005Metric; Manufacturer_Part_Number RMCF0402FT10K0
R100: 0R; R_0402_1005Metric; Manufacturer_Part_Number CR0402AJ/-000GAS
R103: 2m; 3920; Manufacturer_Part_Number SEWF3920D2L00P9
R115: 0R; R_0805_2012Metric; Manufacturer_Part_Number RMCF0805ZT0R00
U18: DMP68D1LVQ-7; SOTFL50P162X60-6N; Manufacturer_Part_Number DMP68D1LVQ-7; Mouser Part Number 621-DMP68D1LVQ-7
U19: TPS12000QDGXRQ1; VSSOP19_DGX_TEX; Manufacturer_Part_Number TPS12000QDGXRQ1

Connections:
+3V3: D15.1 (K), U19.7 (CS_SEL); also elsewhere on the board
/ADC/BATT_CS_POS: R103.2, U19.17 (CS-); also elsewhere on the board
/FETs/BATT_PWR_VCC: F1.1; also elsewhere on the board
/FETs/BATT_PWR_VCC_FUSED: C31.1, D6.1 (A1), F1.2, Q1.5 (D), Q3.2 (S), R90.1, R91.1, R92.1, U19.20 (VS); also elsewhere on the board
/FETs/CHG_PRES: C44.1, D15.2 (A), R116.2, R118.1; also elsewhere on the board
/FETs/DRV_FET_EN: U19.3 (INP); also elsewhere on the board
/FETs/DRV_MAIN_EN: Q5.1 (G), R98.1; also elsewhere on the board
/FETs/DRV_PRE_FET_EN: Q4.1 (G), R96.1; also elsewhere on the board
/FETs/SYS_VCC: C32.2, D7.1 (A1), Q2.5 (D), R116.1, U18.4; also elsewhere on the board
/FETs/~DRV_FLT: U19.5 (~FLT); also elsewhere on the board
GND: C34.2, C44.2, Q4.2 (S), Q5.2 (S), R96.2, R98.2, R99.2, R100.2, R101.2, R102.2, R115.2, R117.2, R118.2, U19.6 (GND); also elsewhere on the board
unnamed: C31.2, C32.1
unnamed: Q1.4 (G), Q2.4 (G), U19.14 (PD), U19.15 (PU)
unnamed: Q3.3 (D), R95.1, R97.1
unnamed: Q3.1 (G), R92.2, R94.1
unnamed: Q4.3 (D), R93.2
unnamed: Q5.3 (D), R94.2
unnamed: R90.2, U18.1
unnamed: R91.2, R93.1, U18.2, U18.5
unnamed: U18.3, U18.6
unnamed: C33.1, U19.12 (BST)
unnamed: R97.2, R117.1, U19.1 (EN/UVLO)
unnamed: R101.1, U19.8 (ISCP)
unnamed: R95.2, R99.1, U19.2 (OV)
unnamed: R100.1, U19.10 (SCP_TEST)
unnamed: C33.2, Q1.1 (S), Q1.2 (S), Q1.3 (S), Q2.1 (S), Q2.2 (S), Q2.3 (S), U19.13 (SRC)
unnamed: C34.1, R102.1, U19.9 (TMR)
SYS_GND: D6.2 (A2), D7.2 (A2), R103.1, R115.1, U19.18 (CS+); also elsewhere on the board

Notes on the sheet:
About: - TPS1200 is main battery switch. It controller power FETs and protect against battery overvoltage, undervoltage and overcurrent Design Parameters: - 7-cell battery, minimum cut-off voltage 2.5V x 7 = 17.5V (set by EN/UVLO and OV resistors) - 7 cell battery, maximum cut-off voltage 4.3V x 7 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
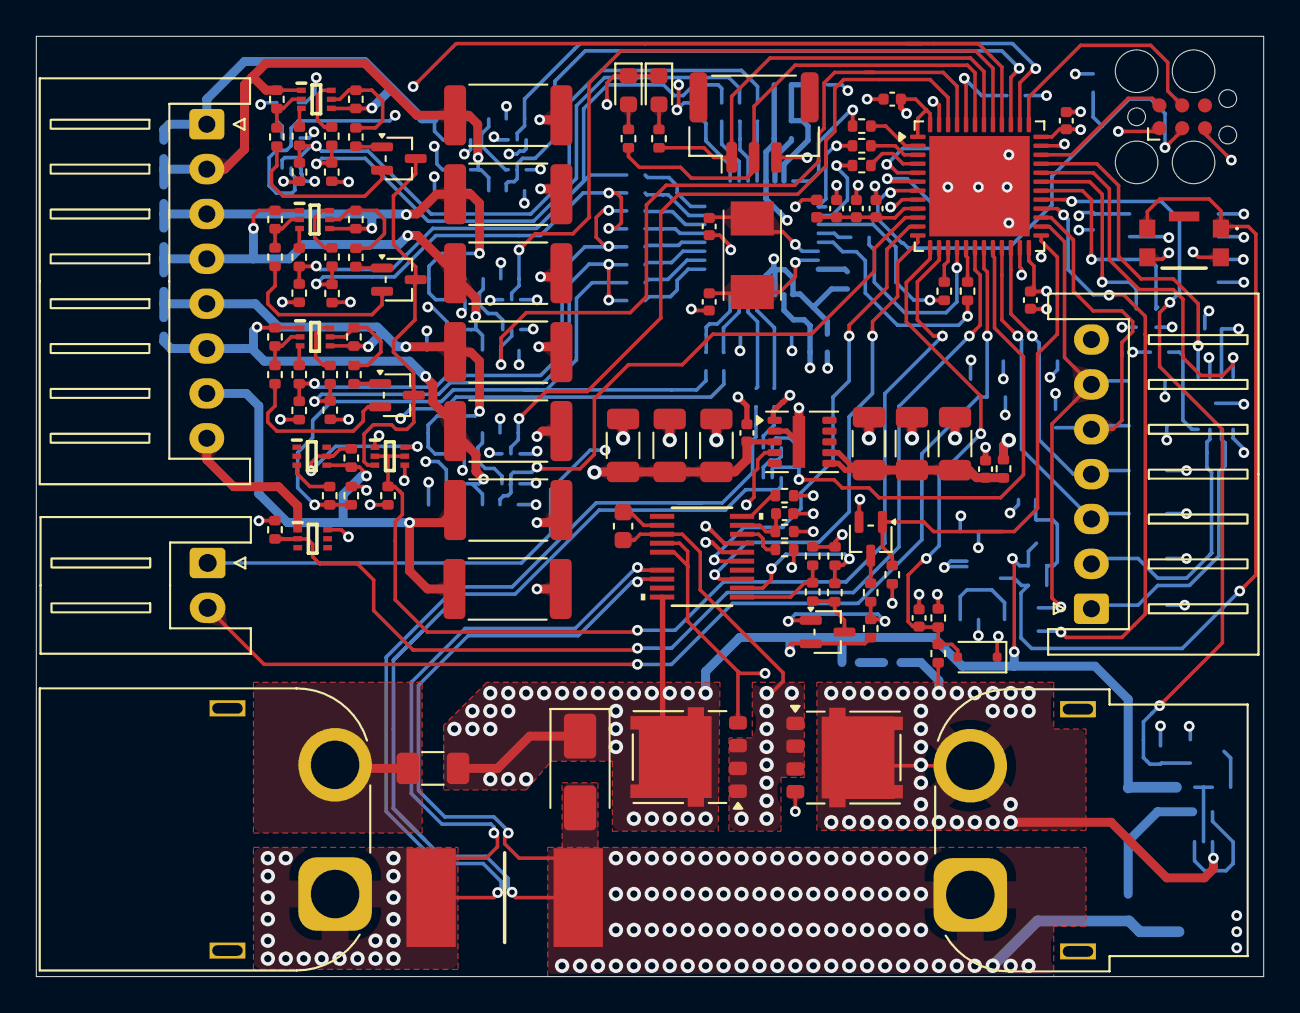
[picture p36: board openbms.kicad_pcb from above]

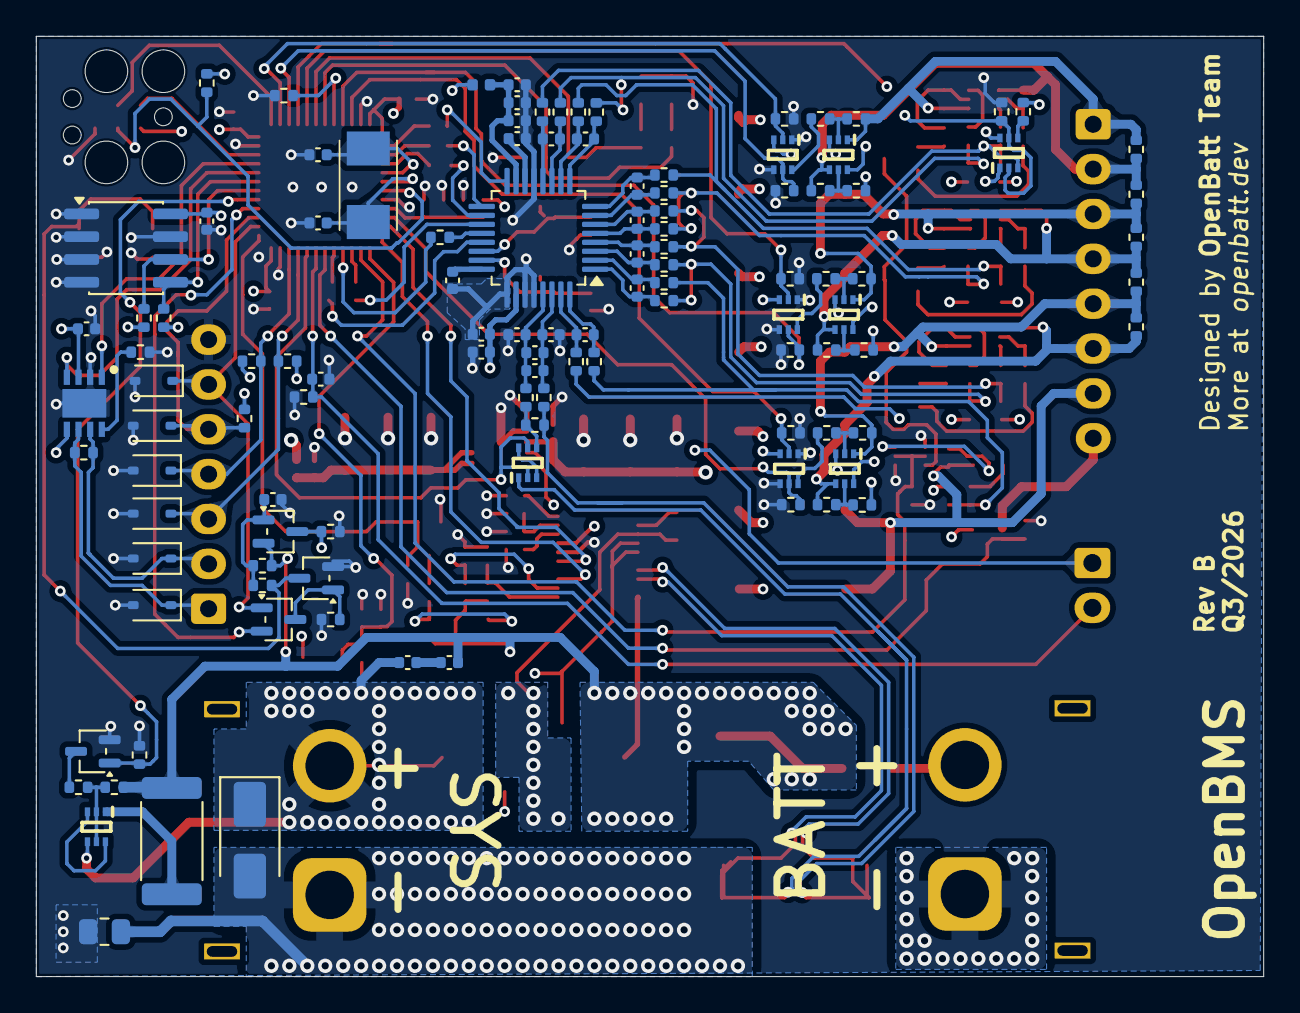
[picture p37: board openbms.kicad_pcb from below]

Board: 4 copper layers, 68.4 x 52.4 mm, 220 parts (113 on the bottom side), 158 nets.

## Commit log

2026-04-16 Initial release, schematic and PCB Layout for Rev A release
    [ADC.kicad_sch, ADS131M08IPBSR.stp, Battery.kicad_sch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]
2026-04-21 Capacitor values in ADC increased from 10n to 100n, production files released
    [ADC.kicad_sch, Battery.kicad_sch, FETs.kicad_sch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]
2026-09-21 Footprints for pmos/nmos and pmos/pmos packages fixed, charger detection added, pwr_gd and flt_gd lines removed
    [ADC.kicad_sch, FETs.kicad_sch, Input.kicad_sch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]
2026-09-22 Resistor dividers updated and put to 0.1% tolerance
    [ADC.kicad_sch, openbms.kicad_pcb, openbms.kicad_sch]
2026-09-22 Option to shortcut current ADC sensor added
    [ADC.kicad_sch, MCU.kicad_sch, openbms.kicad_pcb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]
2026-09-24 Button for quick enable added
    [435451019820.stp, ADC.kicad_sch, FETs.kicad_sch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]
2026-09-24 FET driver EN and OV pin voltage levels fixed
    [FETs.kicad_sch, openbms.kicad_pcb, openbms.kicad_sch]
2026-09-24 Polygon zone fixed, SRC net in FET fixed
    [FETs.kicad_sch, openbms.kicad_pcb, openbms.kicad_sch]
2026-09-24 Green LED part number fixed, PCB mask color updated, project description updated
    [ADC.kicad_sch, FETs.kicad_sch, Input.kicad_sch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]
2026-09-24 Revision B comments added, PDF generated
    [Power.kicad_sch, openbms.kicad_sch]
2026-09-24 Teardrops added, EEPROM part number updated, production files released
    [MCU.kicad_sch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]
2026-09-24 D15 diode parameters updated, BOM updated
    [BOM openbms.csv, FETs.kicad_sch, openbms.csv]
2026-09-25 BOM updates
    [BOM openbms.csv, BOM openbms.xlsx, MCU.kicad_sch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]

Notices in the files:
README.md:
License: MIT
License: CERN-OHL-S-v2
